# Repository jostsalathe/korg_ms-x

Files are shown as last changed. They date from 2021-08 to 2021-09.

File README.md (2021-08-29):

# Korg MS-X

An extreme MONOTRON mod by Soul Machine in form of an SMD PCB.

## credits

The schematics design and build instructions were published by Soul Machine on his project page
[Far Beyond Perception Instruments](https://www.djsoulmachine.com/farbeyondperception/msx.html)
and as 
[PDF here](http://www.djsoulmachine.com/farbeyondperception/msx/MSX-schematics.pdf).

He built it with a lot of perf board and freehand wiring.

Also special thanks to Heiner Büge who convinced me to build this mod with him. He also brought a lot of knowledge about analog synthesizers into this project and I would **not** have been able to develop this project without him!

## Where this project takes over

This project aims to take the design of Soul Machine and develop a neat printed circuit board with SMD components where sensible so that it can be produced and to a large degree even be assembled by cheap manufacturers like [JLCPCB](jlcpcb.com) or [PCBWay](pcbway.com).

## Parts

0805 chip resistors with 1% tolerance shall be used for relatively easy hand soldering.
Most capacitors are cermaic 0805. 100uF (10V) and 47uF (6V3) use 1206 package instead.

### SMD parts

| Part | Count | Refs | JLCPCB # ***extended*** (2021-08-27) |
| --- | --- | --- | --- |
| 100uF | 3 | C201, C303, C403 | ***C312983*** |
| 10uF | 10 | C202, C205-C207, C308, C401, C402, C506, C601, C702 | C15850 |
| 47uF | 2 | C203, C204 | C96123 |
| 1uF | 5 | C301, C302, C304, C305, C701 | C28323 |
| 100nF | 7 | C306, C501, C505, C507-C510 | C49678 |
| 470nF | 1 | C307 | C13967 |
| 22pF | 1 | C309 | C1804 |
| 500pF | 1 | C404 | ***C1747*** |
| 47nF | 1 | C502 | C53134 |
| 4.7nF | 1 | C503 | C1744 |
| 470pF | 1 | C504 | C1743 |
| 100pF | 1 | C703 | C1790 |
| 1N4148 | 4 | D301, D302, D401, D402 | C2128 |
| 2SC945 | 1 | Q701 | ***C181154*** |
| 10k | 22 | R201, R202, R417, R501, R505-R507, R509, R510, R512, R513, R515, R516, R518, R519, R521, R522, R524, R604, R607, R608, R610 | C17414 |
| 100k | 43 | R301-R305, R307, R309-R312, R318, R324-R331, R401, R402, R404, R406-R413, R420, R421, R502, R602, R609, R612-R614, R616, R701-R703, R706 | ***C149504*** |
| 33k | 1 | R306 | C17633 |
| 47 | 1 | R308 | C17714 |
| 5k6 | 2 | R313, R321 | C4382 |
| 4k7 | 1 | R314 | C17673 |
| 1M | 4 | R315, R322, R403, R503 | C17514 |
| 47k | 2 | R316, R618 | C17713 |
| 56k | 1 | R317 | C17756 |
| 12 | 1 | R319 | ***C204200*** |
| 39k | 2 | R320, R419 | C25826 |
| 220k | 1 | R323 | C17556 |
| 22k | 1 | R405 | C17560 |
| 2k2 | 3 | R414-R416 | C17520 |
| 180 | 2 | R418, R504 | C25270 |
| 1k | 11 | R508, R511, R514, R517, R520, R523, R525, R601, R605, R619, R707 | C17513 |
| 56 | 1 | R603 | C17757 |
| 390 | 1 | R606 | C17655 |
| 27k | 1 | R611 | C17593 |
| 330k | 1 | R615 | C17629 |
| 68k | 1 | R617 | C17801 |
| 680k | 1 | R704 | C17797 |
| 470k | 1 | R705 | C17709 |
| 150k | 1 | R708 | C17470 |
| AMS1117-5.0 | 1 | U202 | C6187 |
| LMV321 | 3 | U203, U304, U501 | C7972 |
| ICL7660S | 1 | U204 | ***C7535*** |
| LM324 | 4 | U301, U302, U401, U402 | C71035 |
| CD4040BM/TR | 1 | U303 | ***C725347*** |
| TL082 | 3 | U601, U602, U701 | ***C9385*** |

### THT parts

| Part | Count | Refs |
| --- | --- | --- |
| 10k trimmer pot  | 5 | RV303, RV401, RV601, RV603, RV605  |
| 100k trimmer pot | 3 | RV502, RV504, RV606 |
| DIP-14 IC socket | 1 | U502 |

### external parts

| Part | Count | Refs (optional) |
| --- | --- | --- |
| Korg MONOTRON | 1 | J101 |
| LED | 2 | D403, D501 |
| DC jack | 1 | J201 |
| rotary switch 3P4T | 2 | J301, J601 |
| rotary switch 4P3T | 1 | J401 |
| 1/4" mono jack | 3 | J602, J603, J701 |
| 10k pot | 9..11 | RV301, RV501, RV503, (RV505), (RV506), RV507, RV508, RV509, RV510, RV602, RV701 |
| 100k pot | 1 | RV302 |
| 20k pot | 2 | RV402, RV403 |
| 220k pot | 1 | RV604 |
| toggle switch SPST | 1..4  | (SW501), (SW502), SW601, (SW603) |
| mom. switch SPST | 1 | SW605 |
| toggle switch SP3T | 0..1  | (SW503) |
| toggle switch SPDT | 3..4  | (SW504), SW602, SW604, SW701 |
| mom. switch SPDT | 0..1  | (SW505) |

## Pictures

PCB front:

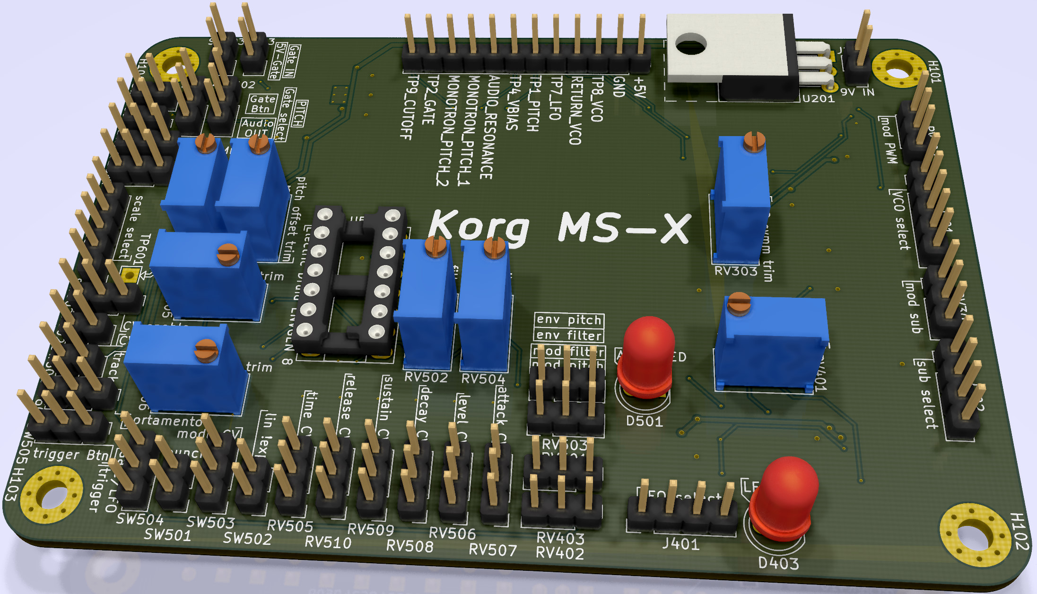
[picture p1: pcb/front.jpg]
PCB front


PCB back:

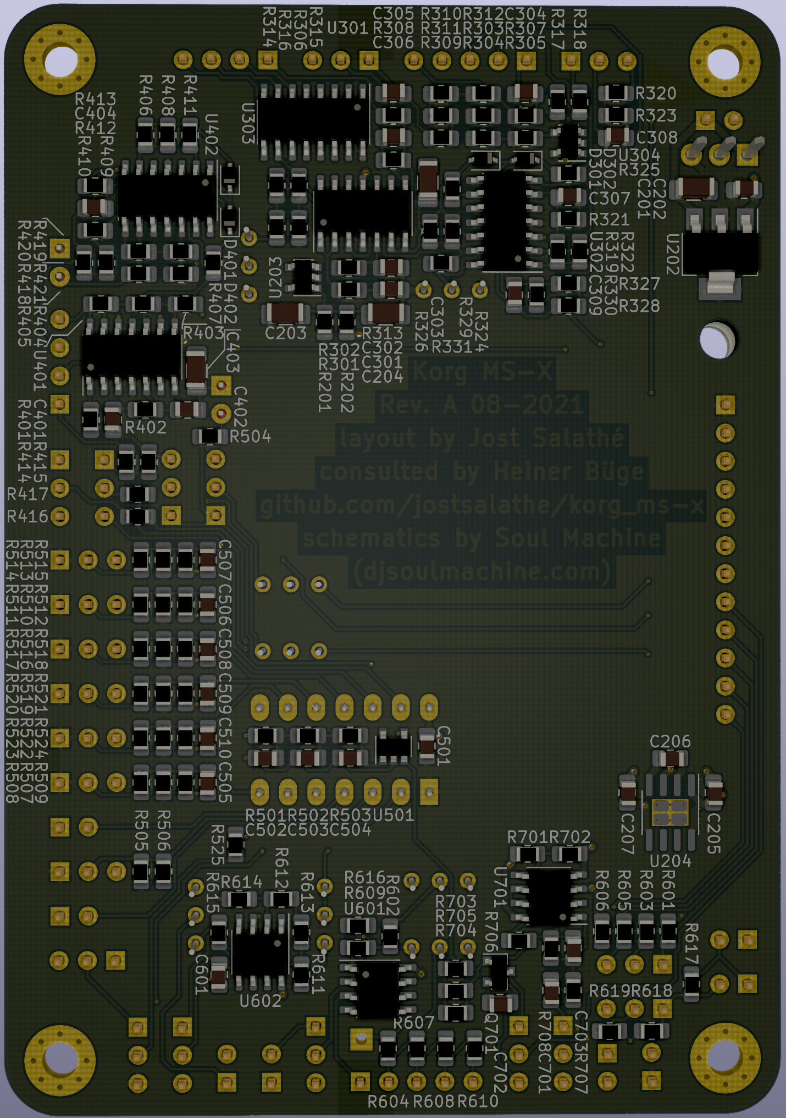
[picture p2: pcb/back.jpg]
PCB back


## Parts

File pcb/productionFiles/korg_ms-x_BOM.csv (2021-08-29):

Comment | Designator | Footprint | LCSC Part Number
100u | C201,C303,C403 | Capacitor_SMD:C_1206_3216Metric_Pad1.42x1.75mm_HandSolder | C312983
10u | C202,C205,C206,C207,C308,C401,C402,C506,C601,C702 | Capacitor_SMD:C_0805_2012Metric_Pad1.18x1.45mm_HandSolder | C15850
47u | C203,C204 | Capacitor_SMD:C_1206_3216Metric_Pad1.42x1.75mm_HandSolder | C96123
1u | C301,C302,C304,C305,C701 | Capacitor_SMD:C_0805_2012Metric_Pad1.18x1.45mm_HandSolder | C28323
100n | C306,C501,C505,C507,C508,C509,C510 | Capacitor_SMD:C_0805_2012Metric_Pad1.18x1.45mm_HandSolder | C49678
470n | C307 | Capacitor_SMD:C_0805_2012Metric_Pad1.18x1.45mm_HandSolder | C13967
22p | C309 | Capacitor_SMD:C_0805_2012Metric_Pad1.18x1.45mm_HandSolder | C1804
500p | C404 | Capacitor_SMD:C_0805_2012Metric_Pad1.18x1.45mm_HandSolder | C1747
47n | C502 | Capacitor_SMD:C_0805_2012Metric_Pad1.18x1.45mm_HandSolder | C53134
4n7 | C503 | Capacitor_SMD:C_0805_2012Metric_Pad1.18x1.45mm_HandSolder | C1744
470p | C504 | Capacitor_SMD:C_0805_2012Metric_Pad1.18x1.45mm_HandSolder | C1743
100p | C703 | Capacitor_SMD:C_0805_2012Metric_Pad1.18x1.45mm_HandSolder | C1790
1N4148WS | D301,D302,D401,D402 | Diode_SMD:D_SOD-323 | C2128
LED | D403,D501 | LED_THT:LED_D5.0mm
MountingHole_Pad | H101,H102,H103,H104 | MountingHole:MountingHole_3.2mm_M3_Pad_Via
MONOTRON | J101 | Connector_PinHeader_2.54mm:PinHeader_1x12_P2.54mm_Vertical
PWR_IN | J201 | Connector_PinHeader_2.54mm:PinHeader_1x02_P2.54mm_Vertical
VCO_SEL | J301 | Connector_PinHeader_2.54mm:PinHeader_1x05_P2.54mm_Vertical
SUB_SEL | J302 | Connector_PinHeader_2.54mm:PinHeader_1x04_P2.54mm_Vertical
LFO_SEL | J401 | Connector_PinHeader_2.54mm:PinHeader_1x04_P2.54mm_Vertical
SCALE_SEL | J601 | Connector_PinHeader_2.54mm:PinHeader_1x05_P2.54mm_Vertical
CV_IN | J602 | Connector_PinHeader_2.54mm:PinHeader_1x02_P2.54mm_Vertical
GATE_IN | J603 | Connector_PinHeader_2.54mm:PinHeader_1x02_P2.54mm_Vertical
AUDIO_OUT | J701 | Connector_PinHeader_2.54mm:PinHeader_1x02_P2.54mm_Vertical
Net-Tie_2 | NT201 | NetTie:NetTie-2_SMD_Pad0.5mm
2SC945 | Q701 | Package_TO_SOT_SMD:SOT-23 | C181154
10k | R201,R202,R417,R501,R505,R506,R507,R509,R510,R512,R513,R515,R516,R518,R519,R521,R522,R524,R604,R607,R608,R610 | Resistor_SMD:R_0805_2012Metric_Pad1.20x1.40mm_HandSolder | C17414
100k | R301,R302,R303,R304,R305,R307,R309,R310,R311,R312,R318,R324,R325,R326,R327,R328,R329,R330,R331,R401,R402,R404,R406,R407,R408,R409,R410,R411,R412,R413,R420,R421,R502,R602,R609,R612,R613,R614,R616,R701,R702,R703,R706 | Resistor_SMD:R_0805_2012Metric_Pad1.20x1.40mm_HandSolder | C149504
33k | R306 | Resistor_SMD:R_0805_2012Metric_Pad1.20x1.40mm_HandSolder | C17633
47 | R308 | Resistor_SMD:R_0805_2012Metric_Pad1.20x1.40mm_HandSolder | C17714
5k6 | R313,R321 | Resistor_SMD:R_0805_2012Metric_Pad1.20x1.40mm_HandSolder | C4382
4k7 | R314 | Resistor_SMD:R_0805_2012Metric_Pad1.20x1.40mm_HandSolder | C17673
1M | R315,R322,R403,R503 | Resistor_SMD:R_0805_2012Metric_Pad1.20x1.40mm_HandSolder | C17514
47k | R316,R618 | Resistor_SMD:R_0805_2012Metric_Pad1.20x1.40mm_HandSolder | C17713
56k | R317 | Resistor_SMD:R_0805_2012Metric_Pad1.20x1.40mm_HandSolder | C17756
12 | R319 | Resistor_SMD:R_0805_2012Metric_Pad1.20x1.40mm_HandSolder | C204200
39k | R320,R419 | Resistor_SMD:R_0805_2012Metric_Pad1.20x1.40mm_HandSolder | C25826
220k | R323 | Resistor_SMD:R_0805_2012Metric_Pad1.20x1.40mm_HandSolder | C17556
22k | R405 | Resistor_SMD:R_0805_2012Metric_Pad1.20x1.40mm_HandSolder | C17560
2k2 | R414,R415,R416 | Resistor_SMD:R_0805_2012Metric_Pad1.20x1.40mm_HandSolder | C17520
180 | R418,R504 | Resistor_SMD:R_0805_2012Metric_Pad1.20x1.40mm_HandSolder | C25270
1k | R508,R511,R514,R517,R520,R523,R525,R601,R605,R619,R707 | Resistor_SMD:R_0805_2012Metric_Pad1.20x1.40mm_HandSolder | C17513
56 | R603 | Resistor_SMD:R_0805_2012Metric_Pad1.20x1.40mm_HandSolder | C17757
390 | R606 | Resistor_SMD:R_0805_2012Metric_Pad1.20x1.40mm_HandSolder | C17655
27k | R611 | Resistor_SMD:R_0805_2012Metric_Pad1.20x1.40mm_HandSolder | C17593
330k | R615 | Resistor_SMD:R_0805_2012Metric_Pad1.20x1.40mm_HandSolder | C17629
68k | R617 | Resistor_SMD:R_0805_2012Metric_Pad1.20x1.40mm_HandSolder | C17801
680k | R704 | Resistor_SMD:R_0805_2012Metric_Pad1.20x1.40mm_HandSolder | C17797
470k | R705 | Resistor_SMD:R_0805_2012Metric_Pad1.20x1.40mm_HandSolder | C17709
150k | R708 | Resistor_SMD:R_0805_2012Metric_Pad1.20x1.40mm_HandSolder | C17470
10k | RV301,RV501,RV503,RV505,RV506,RV507,RV508,RV509,RV510,RV602,RV701 | Connector_PinHeader_2.54mm:PinHeader_1x03_P2.54mm_Vertical
100k | RV302 | Connector_PinHeader_2.54mm:PinHeader_1x03_P2.54mm_Vertical
10k | RV303,RV401,RV601,RV603,RV605 | Potentiometer_THT:Potentiometer_Bourns_3296W_Vertical
20k | RV402,RV403 | Connector_PinHeader_2.54mm:PinHeader_1x03_P2.54mm_Vertical
100k | RV502,RV504,RV606 | Potentiometer_THT:Potentiometer_Bourns_3296W_Vertical
220k | RV604 | Connector_PinHeader_2.54mm:PinHeader_1x03_P2.54mm_Vertical
SW_SPST | SW501,SW502,SW601,SW603,SW605 | Connector_PinHeader_2.54mm:PinHeader_1x02_P2.54mm_Vertical
SW_SPDT_MSM | SW503 | Connector_PinHeader_2.54mm:PinHeader_1x03_P2.54mm_Vertical
SW_SPDT | SW504,SW602,SW604,SW701 | Connector_PinHeader_2.54mm:PinHeader_1x03_P2.54mm_Vertical
SW_Push_SPDT | SW505 | Connector_PinHeader_2.54mm:PinHeader_1x03_P2.54mm_Vertical
scale4V | TP601 | TestPoint:TestPoint_THTPad_2.0x2.0mm_Drill1.0mm
L7805 | U201 | Package_TO_SOT_THT:TO-220-3_Horizontal_TabUp
AMS1117-5.0 | U202 | Package_TO_SOT_SMD:SOT-223-3_TabPin2 | C6187
LM321 | U203,U304,U501 | Package_TO_SOT_SMD:SOT-23-5 | C7972
ICL7660S | U204 | Package_SO:SOIC-8-1EP_3.9x4.9mm_P1.27mm_EP2.41x3.3mm_ThermalVias | C7535
LM324 | U301,U302,U401,U402 | Package_SO:SOIC-14_3.9x8.7mm_P1.27mm | C71035
4040 | U303 | Package_SO:SOIC-16_3.9x9.9mm_P1.27mm | C725347
ENVGEN8 | U502 | Package_DIP:DIP-14_W7.62mm_Socket_LongPads
TL082 | U601,U602,U701 | Package_SO:SOIC-8_3.9x4.9mm_P1.27mm | C9385

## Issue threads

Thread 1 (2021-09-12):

Missing polarity markings on silk screen

jostsalathe, 2021-09-12:
All pin headers should have their polarity marked on the silk screen.

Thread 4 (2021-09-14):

Simulation shows that the portamento stage is unstable

jostsalathe, 2021-09-14:
Because the feedback loop spans across `U602A` and `U602B`, and `U602A.OUT` is not connected to any feedback, that output starts to oscillate on the capacitor `C601` when `U602B.OUT` reaches the level of `pitchSum`.

`R613` should be disconnected from `U602B.IN-` and instead be connected to `U602A.OUT` to fix this behavior.

jostsalathe, 2021-09-14:
Hotfixable by desoldering `R613` and resoldering it between its `R612`-facing pad and `U602.1` which is `U602A.OUT`.

jostsalathe, 2021-09-14:
Nope, that changes the portamento behavior. `U602A.OUT` saturates during portamento to give a more linear response. The suggested change would make the response exponential and much longer, which is not desired.

jostsalathe, 2021-09-14:
Bullocks! I've been hunting ghosts! The actual circuitry has no such oscillation. But we can nontheless implement the `R613` repositioning fix since Heiner approved the logarithmic portamento behavior.

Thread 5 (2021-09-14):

`R611` for pitch gain trim should be larger

jostsalathe, 2021-09-14:
With `R611=27k` and `RV605` at its extreme, an octave on the input only results in about 14 Semitones. Making `R611` a `39k` resistor fixed the issue. This should be corrected in the design.

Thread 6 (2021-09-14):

PWM modulation is filtered too much

jostsalathe, 2021-09-14:
Reduce `C308` from 10uF to 1uF to go from `tau = 2 s` to `tau = 200 ms`.

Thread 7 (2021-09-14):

Replace KB track trimmer (`RV606`) with UI pot

jostsalathe, 2021-09-14:

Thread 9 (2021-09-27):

VCA input circuit is bullshit

jostsalathe, 2021-09-27:
- `R706` should connect `GNDA` to `D701.2` instead.
- `SW701` should be a NO switch that shorts `Q701.3` to `Q701.2` OR one that connects `Q701.1` to `+5VA` via a 1k resistor.
- There should be no directly connected input to `U701A.2`.

jostsalathe, 2021-09-27:
Hotfix will probably add a switch that shorts `Q701.2` to `Q701.3`

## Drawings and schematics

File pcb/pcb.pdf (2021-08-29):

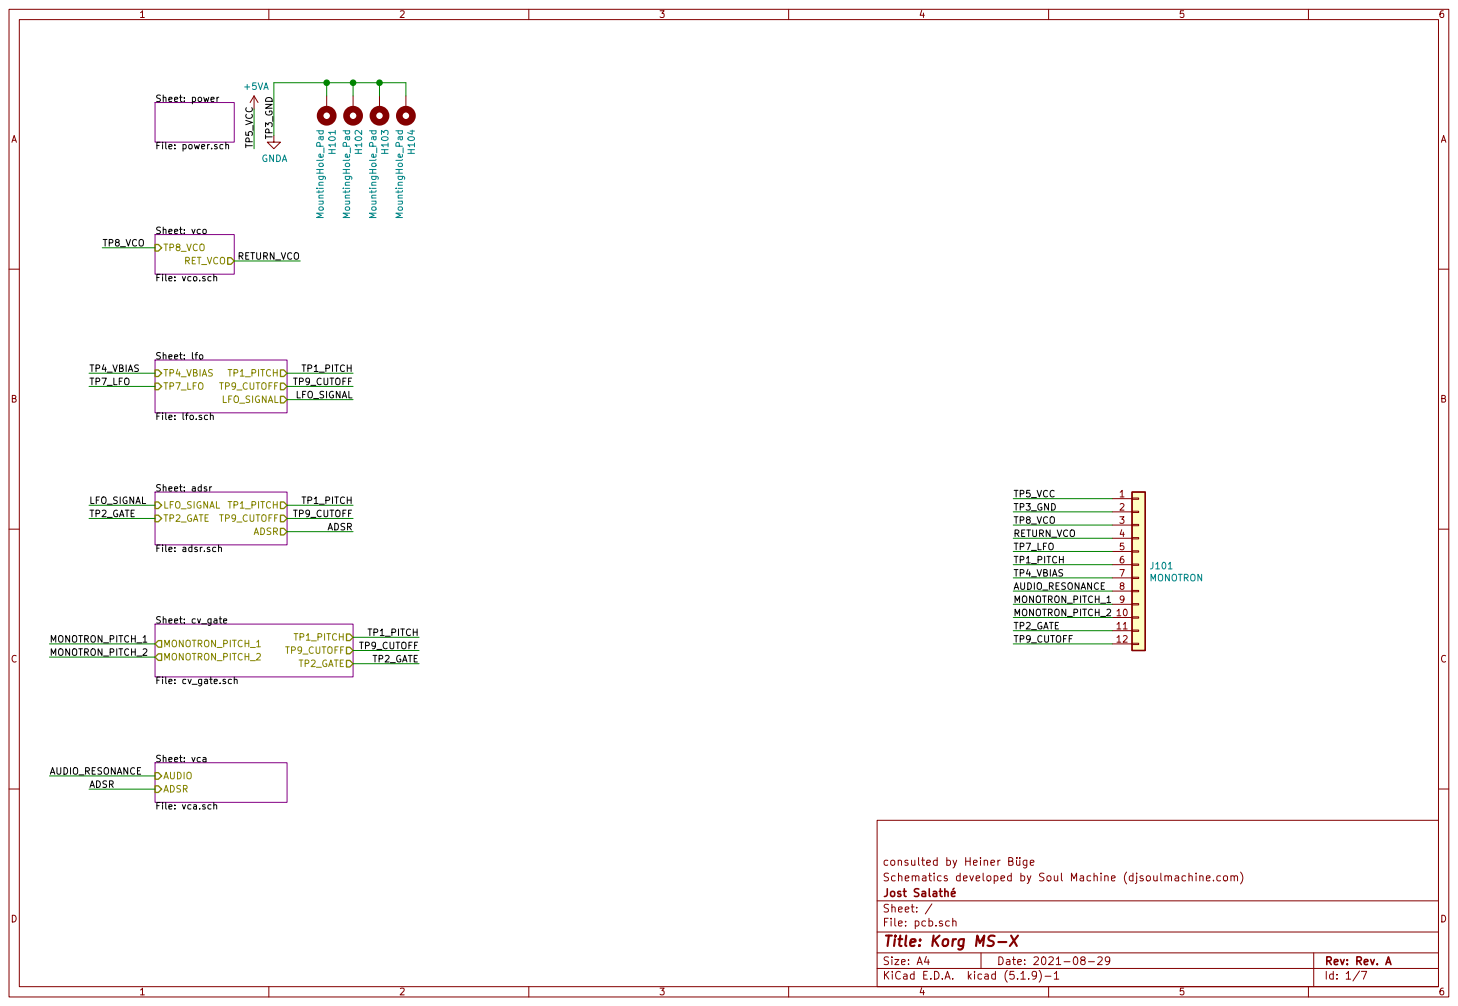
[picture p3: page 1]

Sheet: vco File: vco.sch TP8_VCO

TP2_GATE MONOTRON_PITCH_2 MONOTRON_PITCH_1 Sheet: lfo File: lfo.sch TP7_LFO

LFO_SIGNAL Sheet: adsr File: adsr.sch TP2_GATE TP9_CUTOFF

Sheet: vca File: vca.sch AUDIO

consulted by Heiner Büge
Schematics developed by Soul Machine (djsoulmachine.com)
File: pcb.sch Sheet: / Jost Salathé

Id: 1/7 Title: Korg MS-X

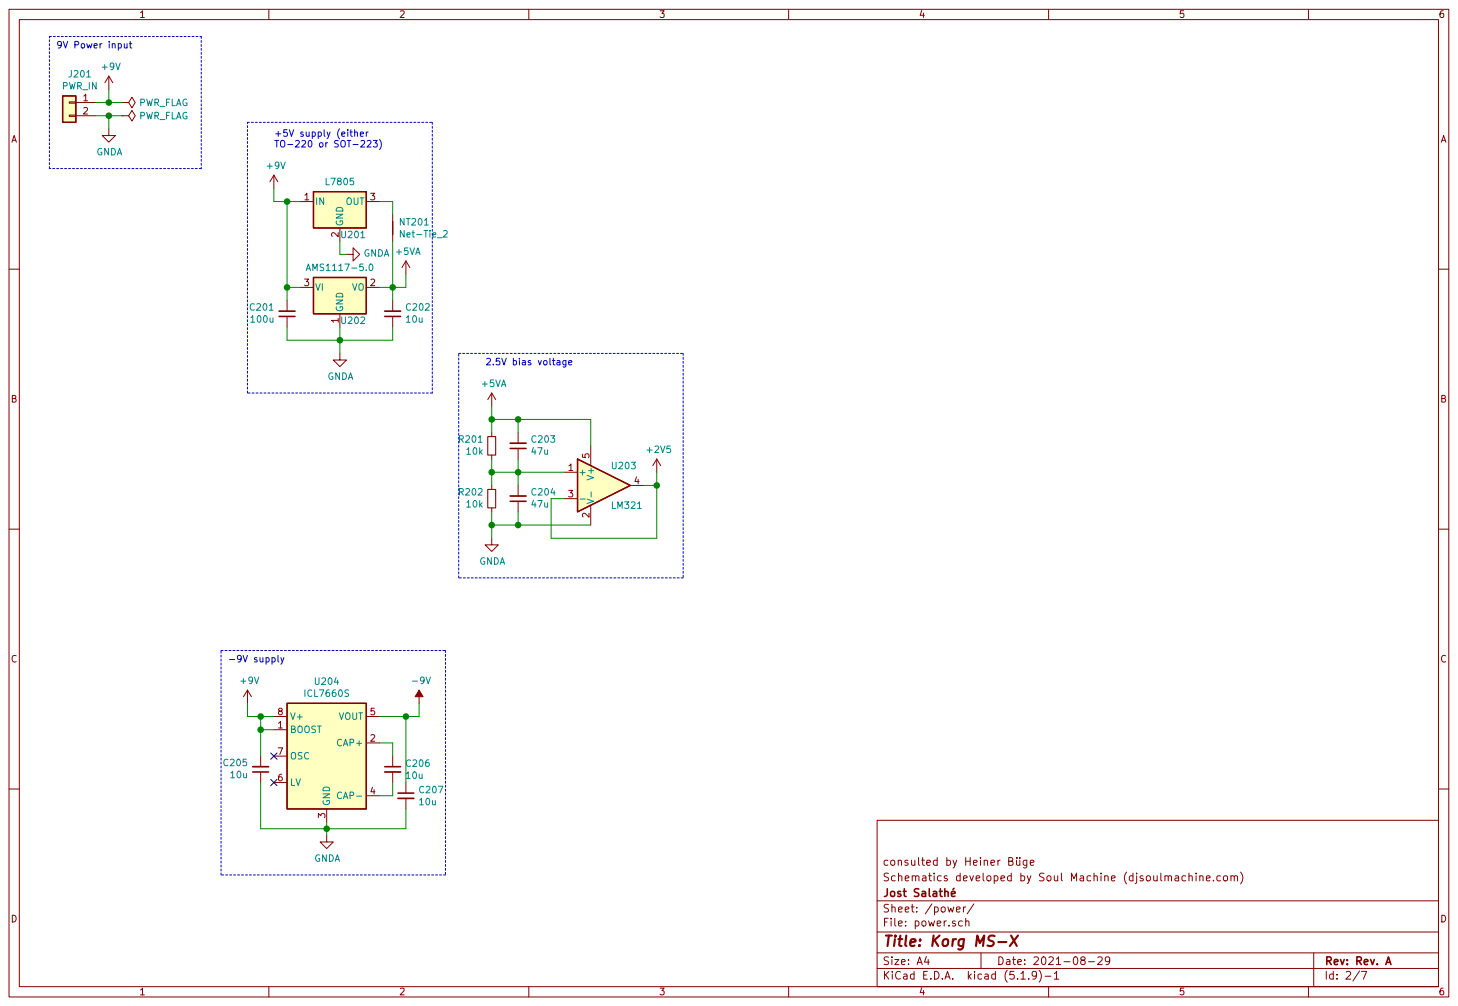
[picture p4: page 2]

consulted by Heiner Büge
Schematics developed by Soul Machine (djsoulmachine.com)
Jost Salathé
Sheet: /power/
File: power.sch
Id: 2/7 Title: Korg MS-X

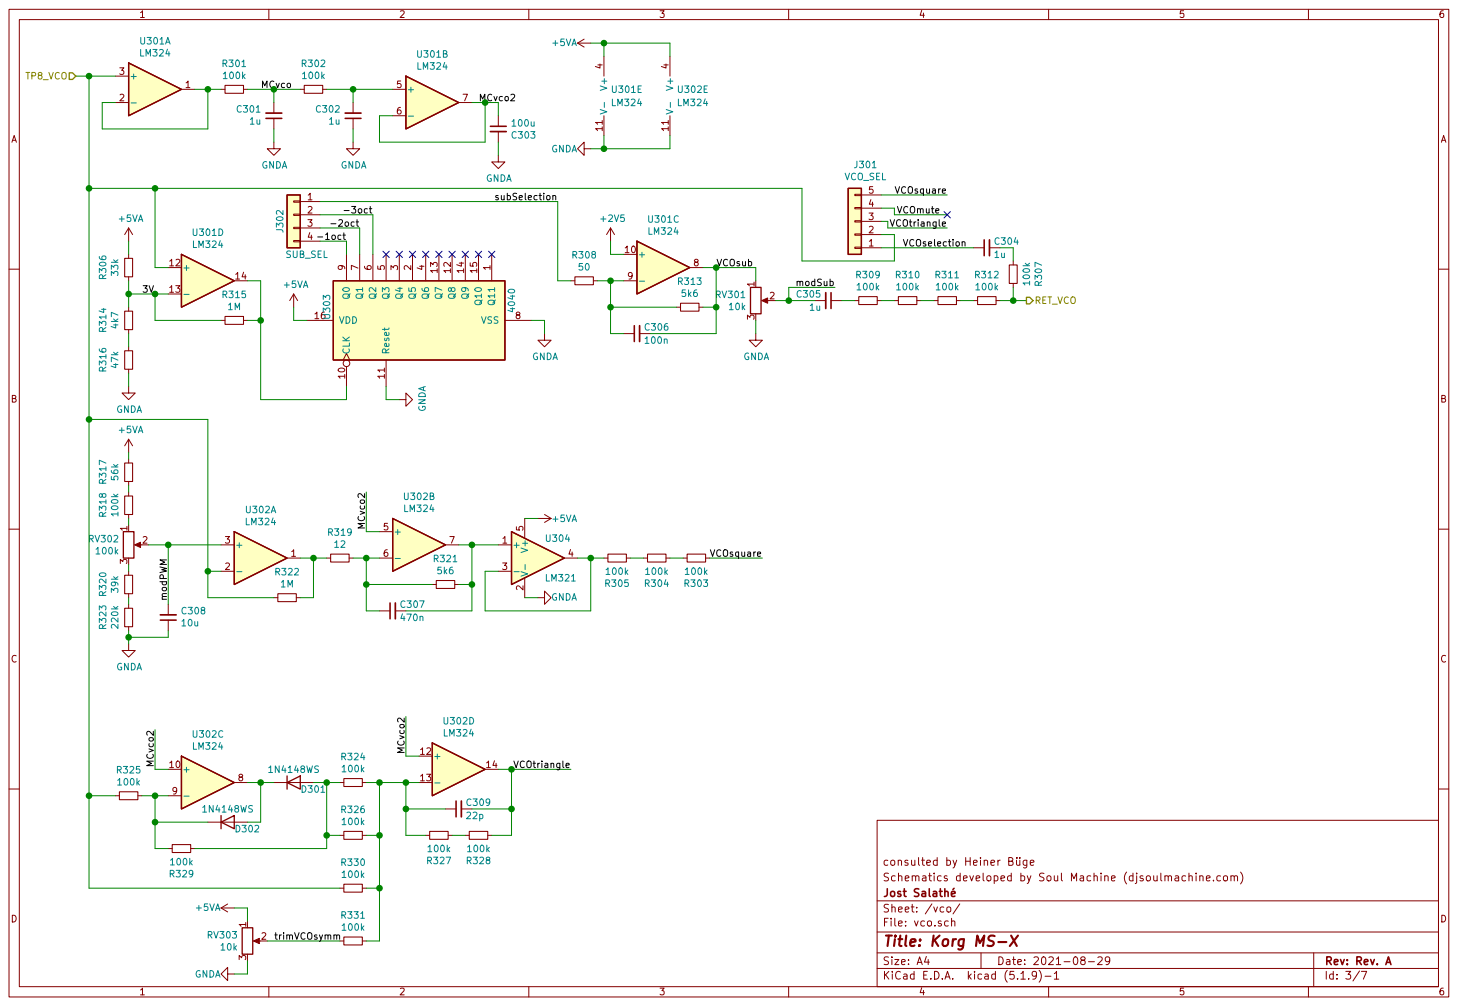
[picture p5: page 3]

consulted by Heiner Büge R326

Schematics developed by Soul Machine (djsoulmachine.com)
File: vco.sch Sheet: /vco/ Jost Salathé

Id: 3/7 Title: Korg MS-X

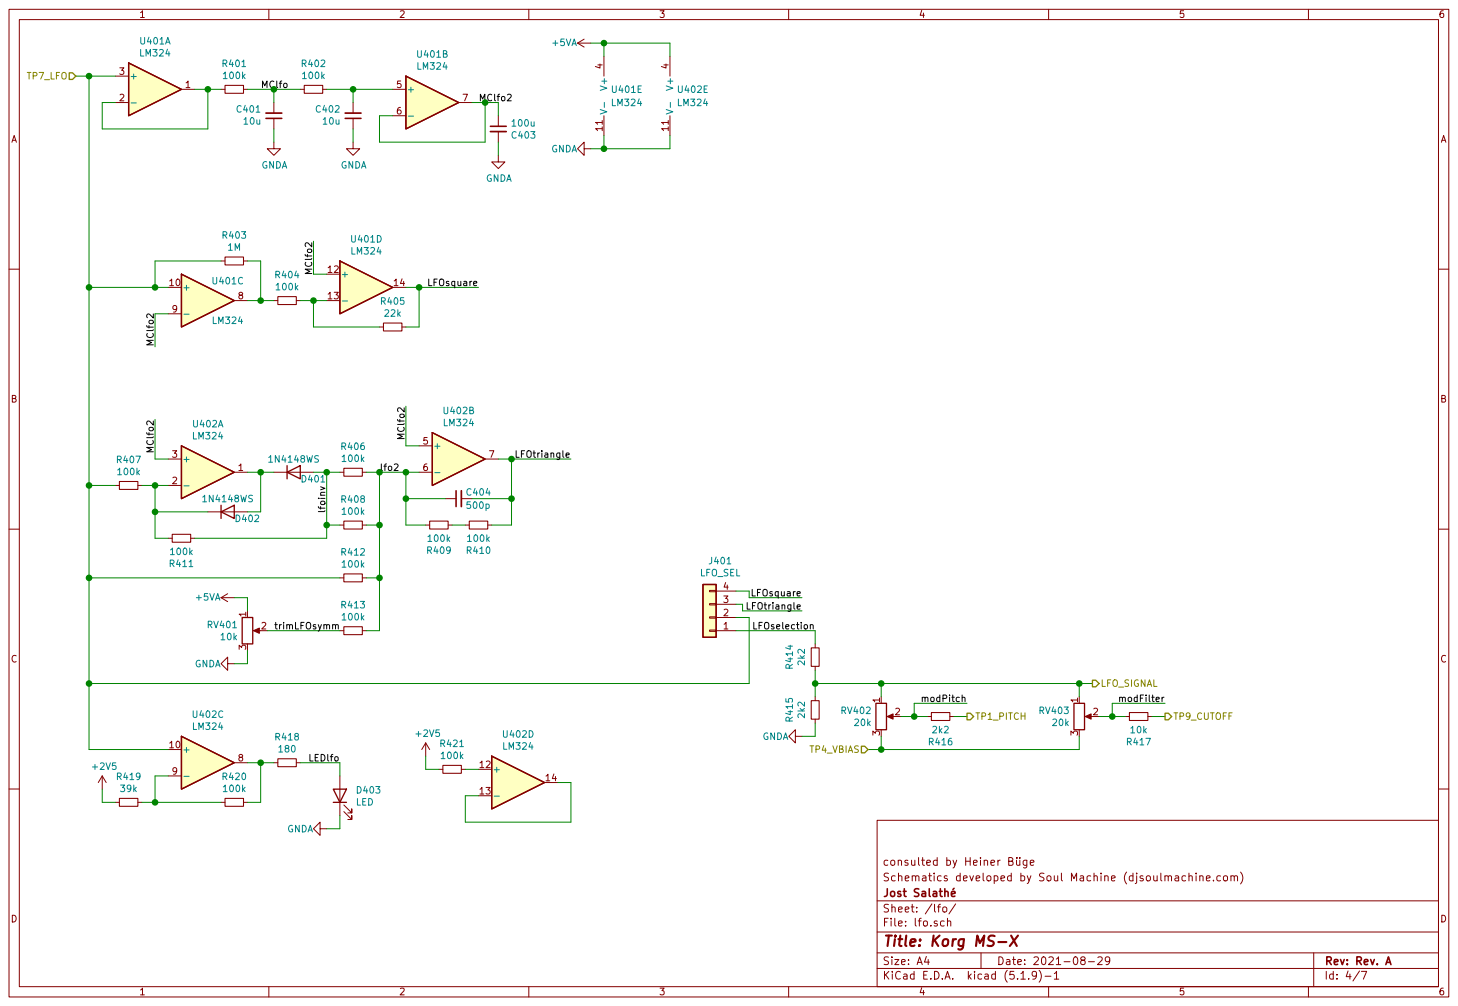
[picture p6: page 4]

consulted by Heiner Büge
Schematics developed by Soul Machine (djsoulmachine.com)
File: lfo.sch Sheet: /lfo/ Jost Salathé

Id: 4/7 Title: Korg MS-X

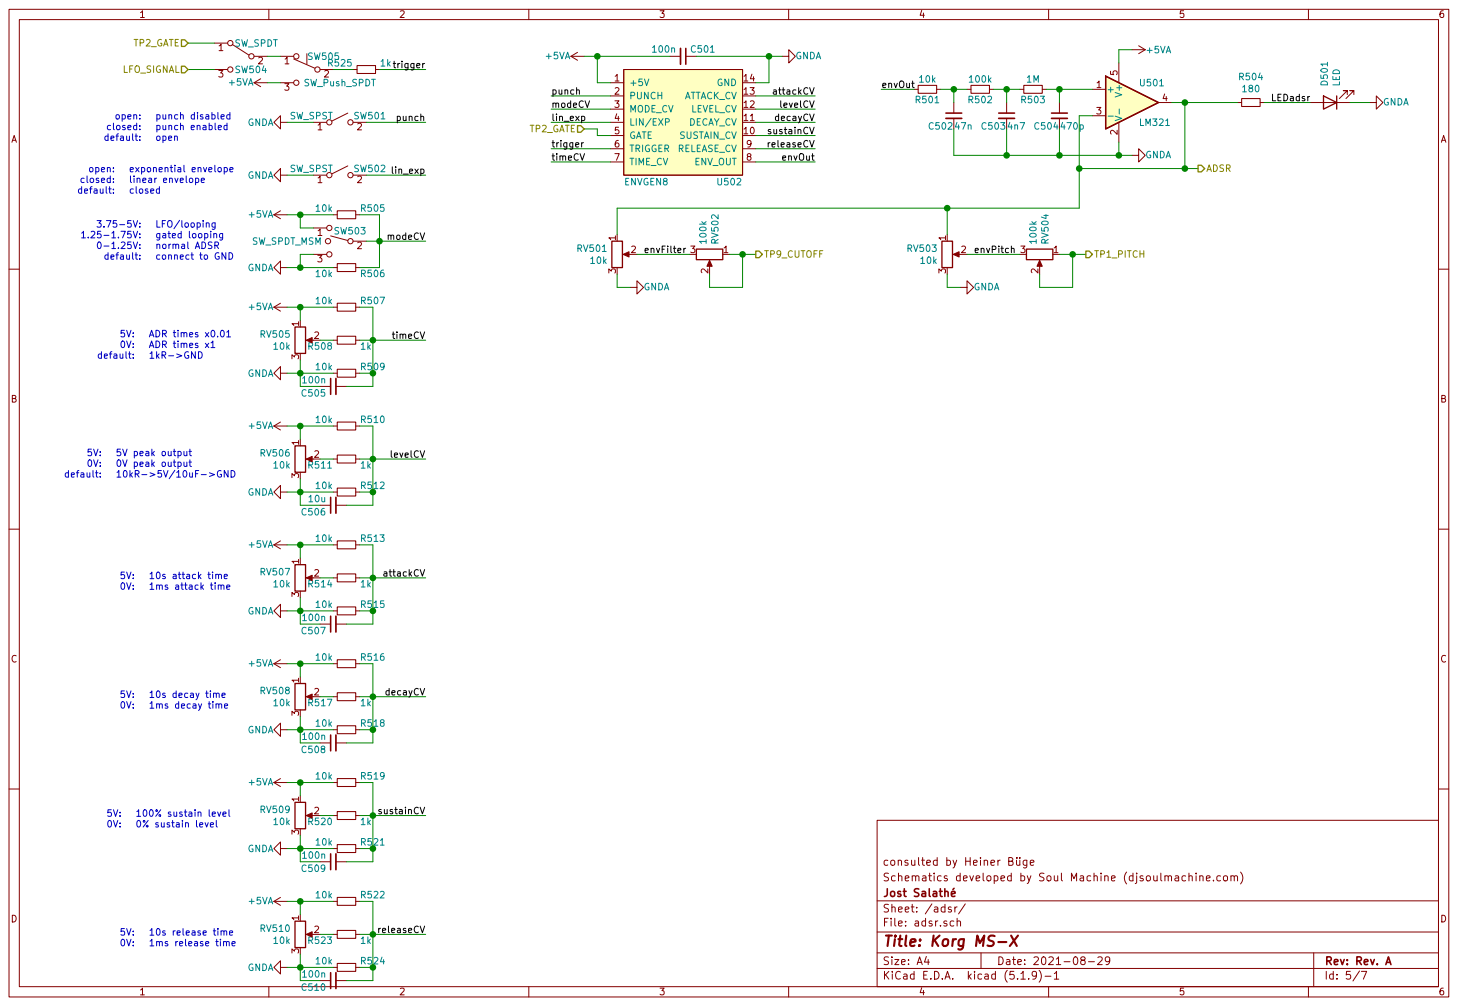
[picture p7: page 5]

TP2_GATE
open: closed: default: 5V: 0V: default: 3.75-5V: 1.25-1.75V: 0-1.25V: default: 5V peak output

exponential envelope
linear envelope
closedADR times x0.01 ADR times x1

consulted by Heiner Büge
Schematics developed by Soul Machine (djsoulmachine.com)
File: adsr.sch Sheet: /adsr/ Jost Salathé

Id: 5/7 Title: Korg MS-X

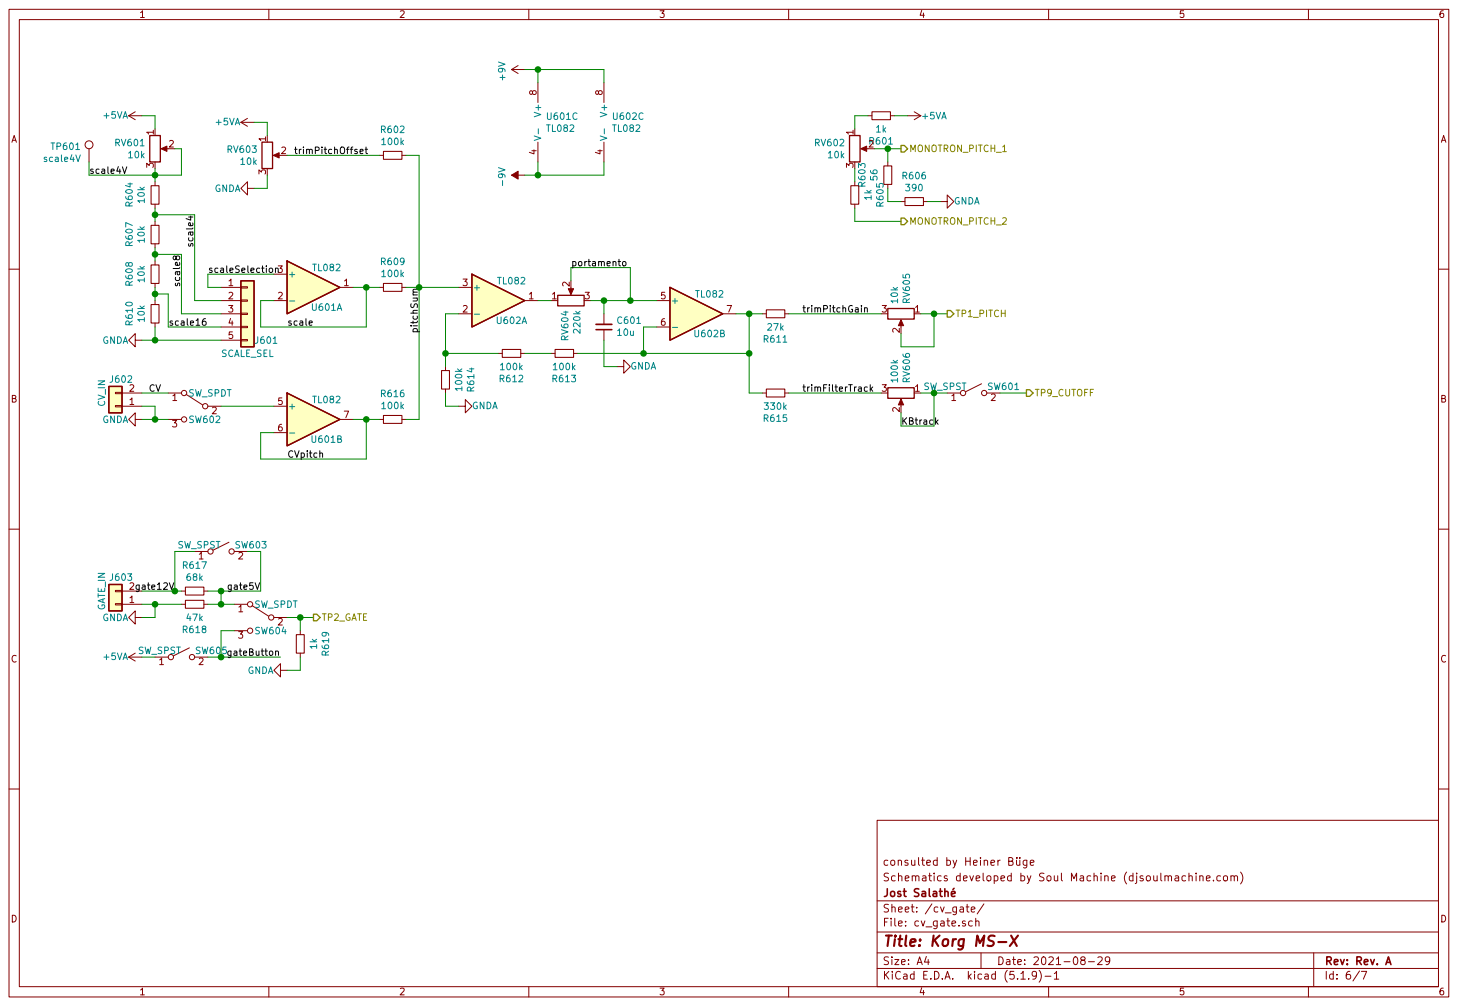
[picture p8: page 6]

consulted by Heiner Büge
Schematics developed by Soul Machine (djsoulmachine.com)
Jost Salathé
Sheet: /cv_gate/
File: cv_gate.sch
Id: 6/7 Title: Korg MS-X

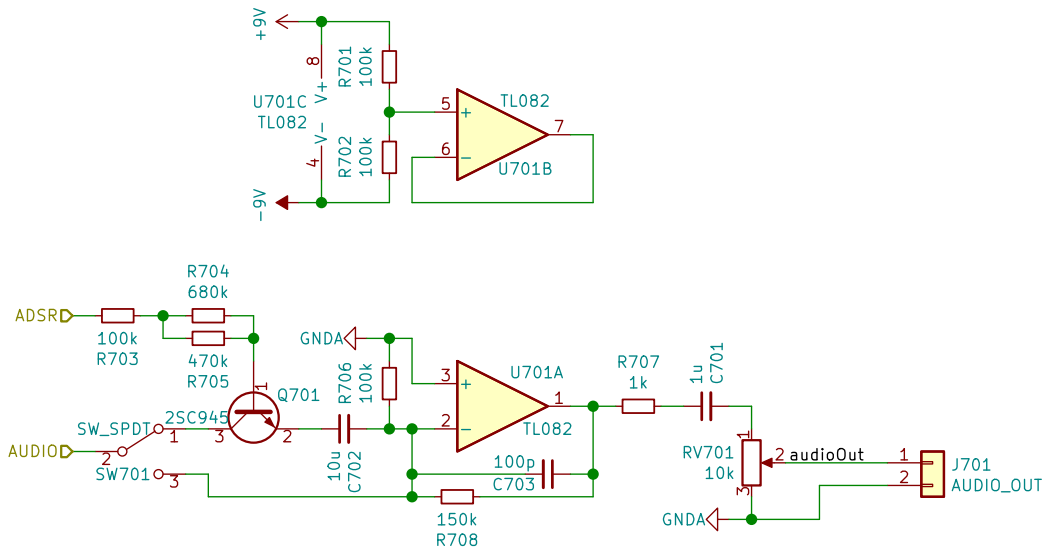
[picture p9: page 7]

consulted by Heiner Büge
Schematics developed by Soul Machine (djsoulmachine.com)
File: vca.sch Sheet: /vca/ Jost Salathé

Id: 7/7 Title: Korg MS-X

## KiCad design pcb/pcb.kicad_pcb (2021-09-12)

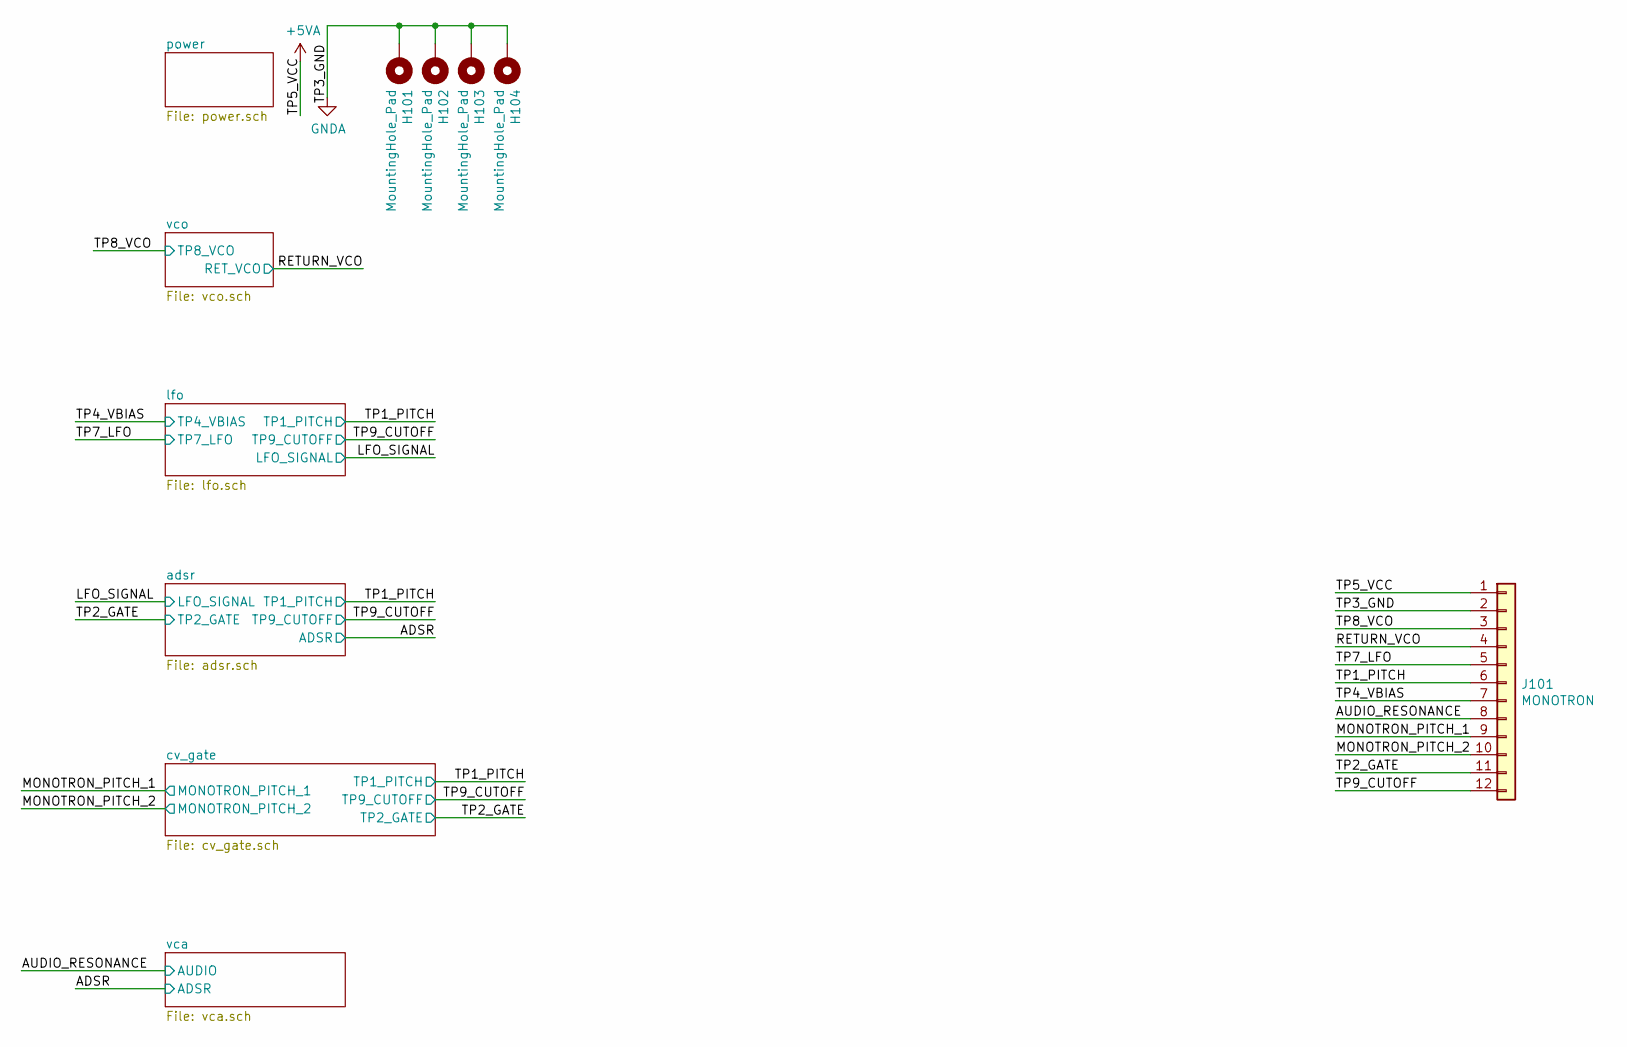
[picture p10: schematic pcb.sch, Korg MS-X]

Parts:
H101, H102, H103, H104: MountingHole_Pad; MountingHole_3.2mm_M3_Pad_Via
J101: MONOTRON; PinHeader_1x12_P2.54mm_Vertical

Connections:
+5VA: J101.1; also elsewhere on the board
/AUDIO_RESONANCE: J101.8; also elsewhere on the board
/MONOTRON_PITCH_1: J101.9; also elsewhere on the board
/MONOTRON_PITCH_2: J101.10; also elsewhere on the board
/RETURN_VCO: J101.4; also elsewhere on the board
/TP1_PITCH: J101.6; also elsewhere on the board
/TP2_GATE: J101.11; also elsewhere on the board
/TP4_VBIAS: J101.7; also elsewhere on the board
/TP7_LFO: J101.5; also elsewhere on the board
/TP8_VCO: J101.3; also elsewhere on the board
/TP9_CUTOFF: J101.12; also elsewhere on the board
GNDA: H101.1, H102.1, H103.1, H104.1, J101.2; also elsewhere on the board

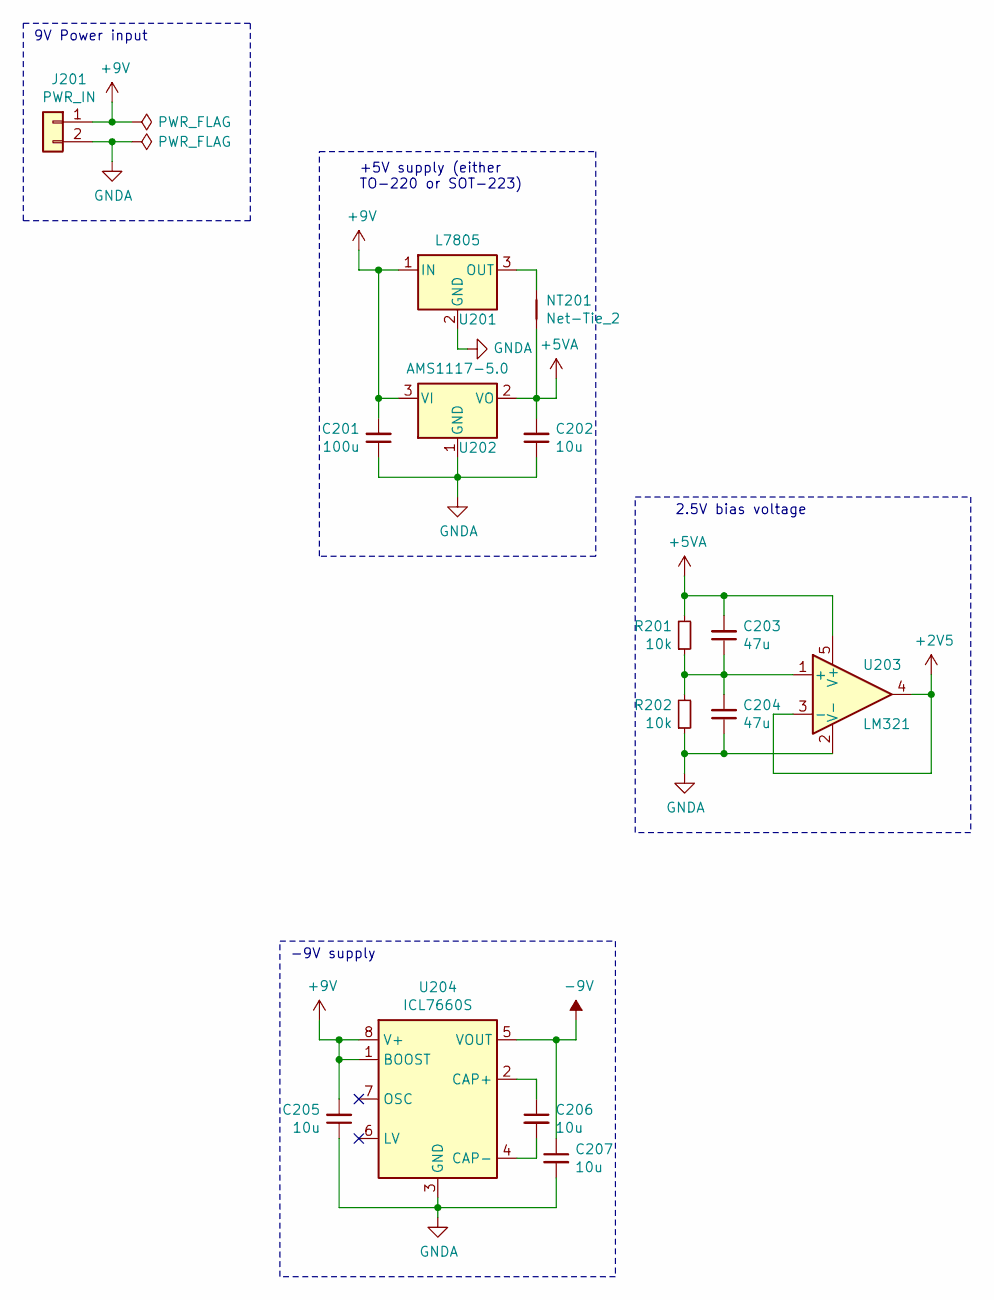
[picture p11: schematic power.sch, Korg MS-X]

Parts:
C201: 100u; C_1206_3216Metric_Pad1.42x1.75mm_HandSolder; LCSC C312983
C202, C205, C206, C207: 10u; C_0805_2012Metric_Pad1.18x1.45mm_HandSolder; LCSC C15850
C203, C204: 47u; C_1206_3216Metric_Pad1.42x1.75mm_HandSolder; LCSC C96123
J201: PWR_IN; PinHeader_1x02_P2.54mm_Vertical
NT201: Net-Tie_2; NetTie-2_SMD_Pad0.5mm
R201, R202: 10k; R_0805_2012Metric_Pad1.20x1.40mm_HandSolder; LCSC C17414
U201: L7805; TO-220-3_Horizontal_TabUp
U202: AMS1117-5.0; SOT-223-3_TabPin2; LCSC C6187
U203: LM321; SOT-23-5; LCSC C7972
U204: ICL7660S; SOIC-8-1EP_3.9x4.9mm_P1.27mm_EP2.41x3.3mm_ThermalVias; LCSC C7535

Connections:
+2V5: U203.3 (-), U203.4; also elsewhere on the board
+5VA: C202.2, C203.2, NT201.2, R201.2, U202.2 (VO), U203.5 (V+); also elsewhere on the board
+9V: C201.2, C205.2, J201.1, U201.1 (IN), U202.3 (VI), U204.1 (BOOST), U204.8 (V+); also elsewhere on the board
-9V: C207.1, U204.5 (VOUT); also elsewhere on the board
GNDA: C201.1, C202.1, C204.1, C205.1, C207.2, J201.2, R202.1, U201.2 (GND), U202.1 (GND), U203.2 (V-), U204.3 (GND); also elsewhere on the board
unnamed: C203.1, C204.2, R201.1, R202.2, U203.1 (+)
unnamed: C206.1, U204.2 (CAP+)
unnamed: C206.2, U204.4 (CAP-)
unnamed: NT201.1, U201.3 (OUT)

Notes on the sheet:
9V Power input
-9V supply
+5V supply (either TO-220 or SOT-223)
2.5V bias voltage

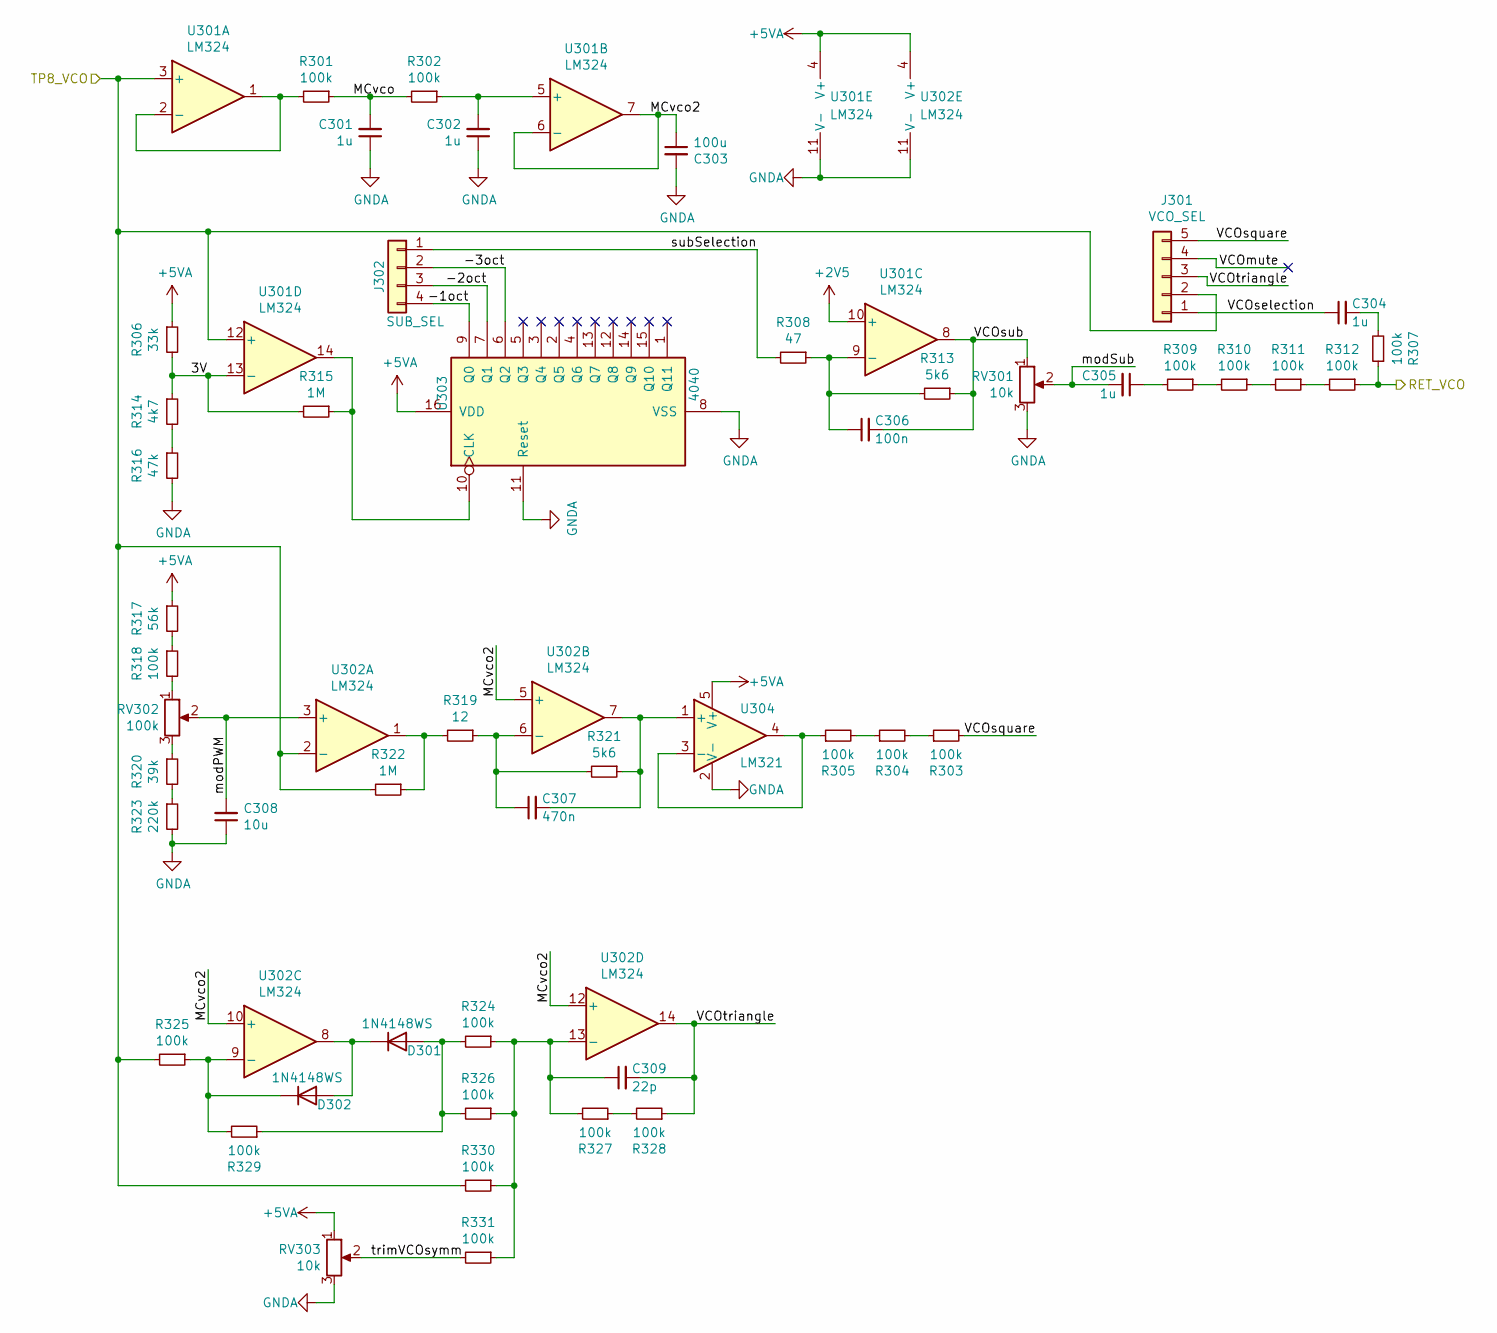
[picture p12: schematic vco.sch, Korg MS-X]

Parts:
C301, C302, C304, C305: 1u; C_0805_2012Metric_Pad1.18x1.45mm_HandSolder; LCSC C28323
C303: 100u; C_1206_3216Metric_Pad1.42x1.75mm_HandSolder; LCSC C312983
C306: 100n; C_0805_2012Metric_Pad1.18x1.45mm_HandSolder; LCSC C49678
C307: 470n; C_0805_2012Metric_Pad1.18x1.45mm_HandSolder; LCSC C13967
C308: 10u; C_0805_2012Metric_Pad1.18x1.45mm_HandSolder; LCSC C15850
C309: 22p; C_0805_2012Metric_Pad1.18x1.45mm_HandSolder; LCSC C1804
D301, D302: 1N4148WS; D_SOD-323; LCSC C2128
J301: VCO_SEL; PinHeader_1x05_P2.54mm_Vertical
J302: SUB_SEL; PinHeader_1x04_P2.54mm_Vertical
R301, R302, R303, R304, R305, R307, R309, R310, R311, R312, R318, R324, R325, R326, R327, R328, R329, R330, R331: 100k; R_0805_2012Metric_Pad1.20x1.40mm_HandSolder; LCSC C149504
R306: 33k; R_0805_2012Metric_Pad1.20x1.40mm_HandSolder; LCSC C17633
R308: 47; R_0805_2012Metric_Pad1.20x1.40mm_HandSolder; LCSC C131893
R313, R321: 5k6; R_0805_2012Metric_Pad1.20x1.40mm_HandSolder; LCSC C4382
R314: 4k7; R_0805_2012Metric_Pad1.20x1.40mm_HandSolder; LCSC C17673
R315, R322: 1M; R_0805_2012Metric_Pad1.20x1.40mm_HandSolder; LCSC C17514
R316: 47k; R_0805_2012Metric_Pad1.20x1.40mm_HandSolder; LCSC C17713
R317: 56k; R_0805_2012Metric_Pad1.20x1.40mm_HandSolder; LCSC C17756
R319: 12; R_0805_2012Metric_Pad1.20x1.40mm_HandSolder; LCSC C204200
R320: 39k; R_0805_2012Metric_Pad1.20x1.40mm_HandSolder; LCSC C25826
R323: 220k; R_0805_2012Metric_Pad1.20x1.40mm_HandSolder; LCSC C17556
RV301: 10k; PinHeader_1x03_P2.54mm_Vertical
RV302: 100k; PinHeader_1x03_P2.54mm_Vertical
RV303: 10k; Potentiometer_Bourns_3296W_Vertical
U301, U302: LM324; SOIC-14_3.9x8.7mm_P1.27mm; LCSC C71035
U303: 4040; SOIC-16_3.9x9.9mm_P1.27mm; LCSC C725347
U304: LM321; SOT-23-5; LCSC C7972

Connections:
+2V5: U301.10 (+); also elsewhere on the board
+5VA: R306.1, R317.1, RV303.1, U301.4 (V+), U302.4 (V+), U303.16 (VDD), U304.5 (V+); also elsewhere on the board
/RETURN_VCO: R307.1, R312.1; also elsewhere on the board
/TP8_VCO: J301.2, R322.2, R325.2, R330.2, U301.3 (+), U301.12 (+), U302.2 (-); also elsewhere on the board
/vco/3V: R306.2, R314.1, R315.2, U301.13 (-)
/vco/-1oct: J302.4, U303.9 (Q0)
/vco/-2oct: J302.3, U303.7 (Q1)
/vco/-3oct: J302.2, U303.6 (Q2)
/vco/MCvco: C301.2, R301.1, R302.2
/vco/MCvco2: C303.1, U301.6 (-), U301.7, U302.5 (+), U302.10 (+), U302.12 (+)
/vco/VCOmute: J301.4
/vco/VCOselection: C304.1, J301.1
/vco/VCOsquare: J301.5, R303.2
/vco/VCOsub: C306.2, R313.1, RV301.1, U301.8
/vco/VCOtriangle: C309.2, J301.3, R328.1, U302.14
/vco/modPWM: C308.2, RV302.2, U302.3 (+)
/vco/modSub: C305.2, RV301.2
/vco/subSelection: J302.1, R308.2
/vco/trimVCOsymm: R331.2, RV303.2
GNDA: C301.1, C302.1, C303.2, C308.1, R316.2, R323.2, RV301.3, RV303.3, U301.11 (V-), U302.11 (V-), U303.8 (VSS), U303.11 (Reset), U304.2 (V-); also elsewhere on the board
unnamed: C302.2, R302.1, U301.5 (+)
unnamed: C304.2, R307.2
unnamed: C305.1, R309.2
unnamed: C306.1, R308.1, R313.2, U301.9 (-)
unnamed: C307.1, R319.1, R321.2, U302.6 (-)
unnamed: C307.2, R321.1, U302.7, U304.1 (+)
unnamed: C309.1, R324.1, R326.1, R327.2, R330.1, R331.1, U302.13 (-)
unnamed: D301.1 (K), D302.2 (A), U302.8
unnamed: D301.2 (A), R324.2, R326.2, R329.1
unnamed: D302.1 (K), R325.1, R329.2, U302.9 (-)
unnamed: R301.2, U301.1, U301.2 (-)
unnamed: R303.1, R304.2
unnamed: R304.1, R305.2
unnamed: R305.1, U304.3 (-), U304.4
unnamed: R309.1, R310.2
unnamed: R310.1, R311.2
unnamed: R311.1, R312.2
unnamed: R314.2, R316.1
unnamed: R315.1, U301.14, U303.10 (CLK)
unnamed: R317.2, R318.1
unnamed: R318.2, RV302.1
unnamed: R319.2, R322.1, U302.1
unnamed: R320.1, RV302.3
unnamed: R320.2, R323.1
unnamed: R327.1, R328.2

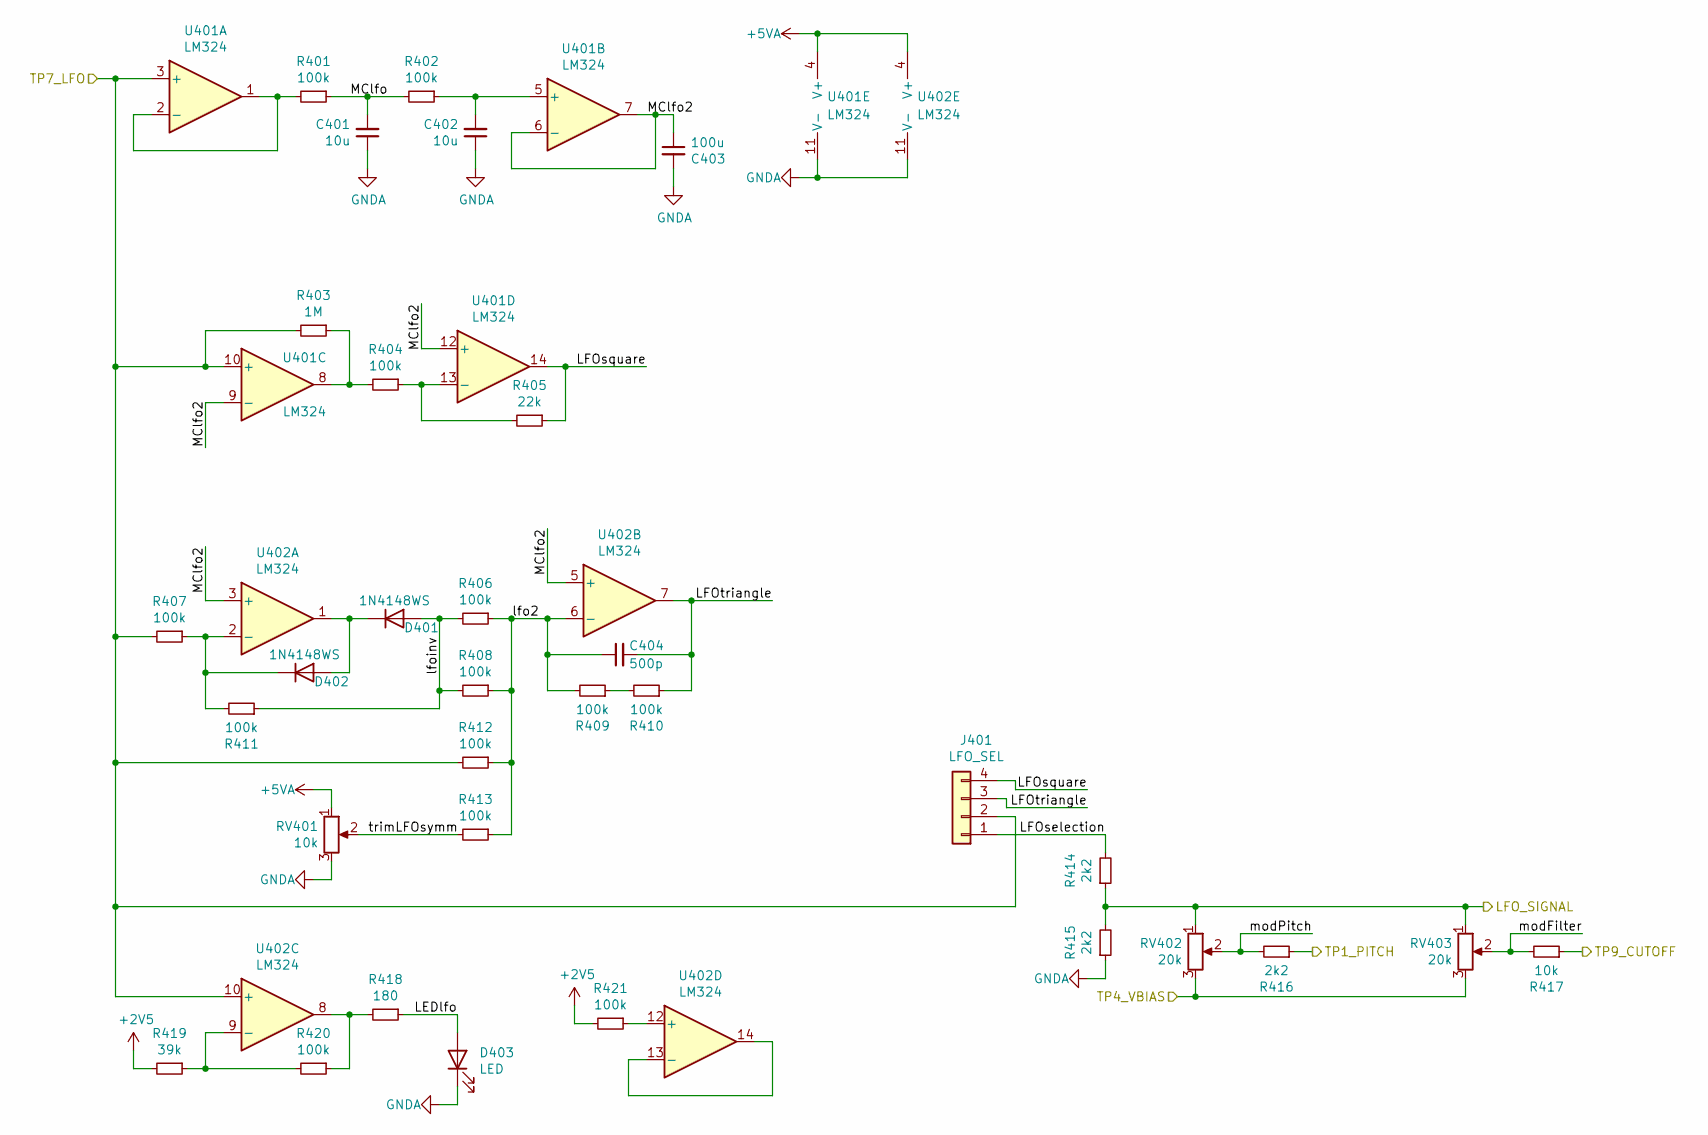
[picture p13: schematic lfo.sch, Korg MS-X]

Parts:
C401, C402: 10u; C_0805_2012Metric_Pad1.18x1.45mm_HandSolder; LCSC C15850
C403: 100u; C_1206_3216Metric_Pad1.42x1.75mm_HandSolder; LCSC C312983
C404: 500p; C_0805_2012Metric_Pad1.18x1.45mm_HandSolder; LCSC C1747
D401, D402: 1N4148WS; D_SOD-323; LCSC C2128
D403: LED; LED_D5.0mm
J401: LFO_SEL; PinHeader_1x04_P2.54mm_Vertical
R401, R402, R404, R406, R407, R408, R409, R410, R411, R412, R413, R420, R421: 100k; R_0805_2012Metric_Pad1.20x1.40mm_HandSolder; LCSC C149504
R403: 1M; R_0805_2012Metric_Pad1.20x1.40mm_HandSolder; LCSC C17514
R405: 22k; R_0805_2012Metric_Pad1.20x1.40mm_HandSolder; LCSC C17560
R414, R415, R416: 2k2; R_0805_2012Metric_Pad1.20x1.40mm_HandSolder; LCSC C17520
R417: 10k; R_0805_2012Metric_Pad1.20x1.40mm_HandSolder; LCSC C17414
R418: 180; R_0805_2012Metric_Pad1.20x1.40mm_HandSolder; LCSC C25270
R419: 39k; R_0805_2012Metric_Pad1.20x1.40mm_HandSolder; LCSC C25826
RV401: 10k; Potentiometer_Bourns_3296W_Vertical
RV402, RV403: 20k; PinHeader_1x03_P2.54mm_Vertical
U401, U402: LM324; SOIC-14_3.9x8.7mm_P1.27mm; LCSC C71035

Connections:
+2V5: R419.2, R421.2; also elsewhere on the board
+5VA: RV401.1, U401.4 (V+), U402.4 (V+); also elsewhere on the board
/LFO_SIGNAL: R414.1, R415.2, RV402.1, RV403.1; also elsewhere on the board
/TP1_PITCH: R416.1; also elsewhere on the board
/TP4_VBIAS: RV402.3, RV403.3; also elsewhere on the board
/TP7_LFO: J401.2, R403.2, R407.2, R412.2, U401.3 (+), U401.10 (+), U402.10 (+); also elsewhere on the board
/TP9_CUTOFF: R417.1; also elsewhere on the board
/lfo/LEDlfo: D403.2 (A), R418.1
/lfo/LFOselection: J401.1, R414.2
/lfo/LFOsquare: J401.4, R405.1, U401.14
/lfo/LFOtriangle: C404.2, J401.3, R410.1, U402.7
/lfo/MClfo: C401.2, R401.1, R402.2
/lfo/MClfo2: C403.1, U401.6 (-), U401.7, U401.9 (-), U401.12 (+), U402.3 (+), U402.5 (+)
/lfo/lfo2: C404.1, R406.1, R408.1, R409.2, R412.1, R413.1, U402.6 (-)
/lfo/lfoinv: D401.2 (A), R406.2, R408.2, R411.1
/lfo/modFilter: R417.2, RV403.2
/lfo/modPitch: R416.2, RV402.2
/lfo/trimLFOsymm: R413.2, RV401.2
GNDA: C401.1, C402.1, C403.2, D403.1 (K), R415.1, RV401.3, U401.11 (V-), U402.11 (V-); also elsewhere on the board
unnamed: C402.2, R402.1, U401.5 (+)
unnamed: D401.1 (K), D402.2 (A), U402.1
unnamed: D402.1 (K), R407.1, R411.2, U402.2 (-)
unnamed: R401.2, U401.1, U401.2 (-)
unnamed: R403.1, R404.2, U401.8
unnamed: R404.1, R405.2, U401.13 (-)
unnamed: R409.1, R410.2
unnamed: R418.2, R420.1, U402.8
unnamed: R419.1, R420.2, U402.9 (-)
unnamed: R421.1, U402.12 (+)
unnamed: U402.13 (-), U402.14

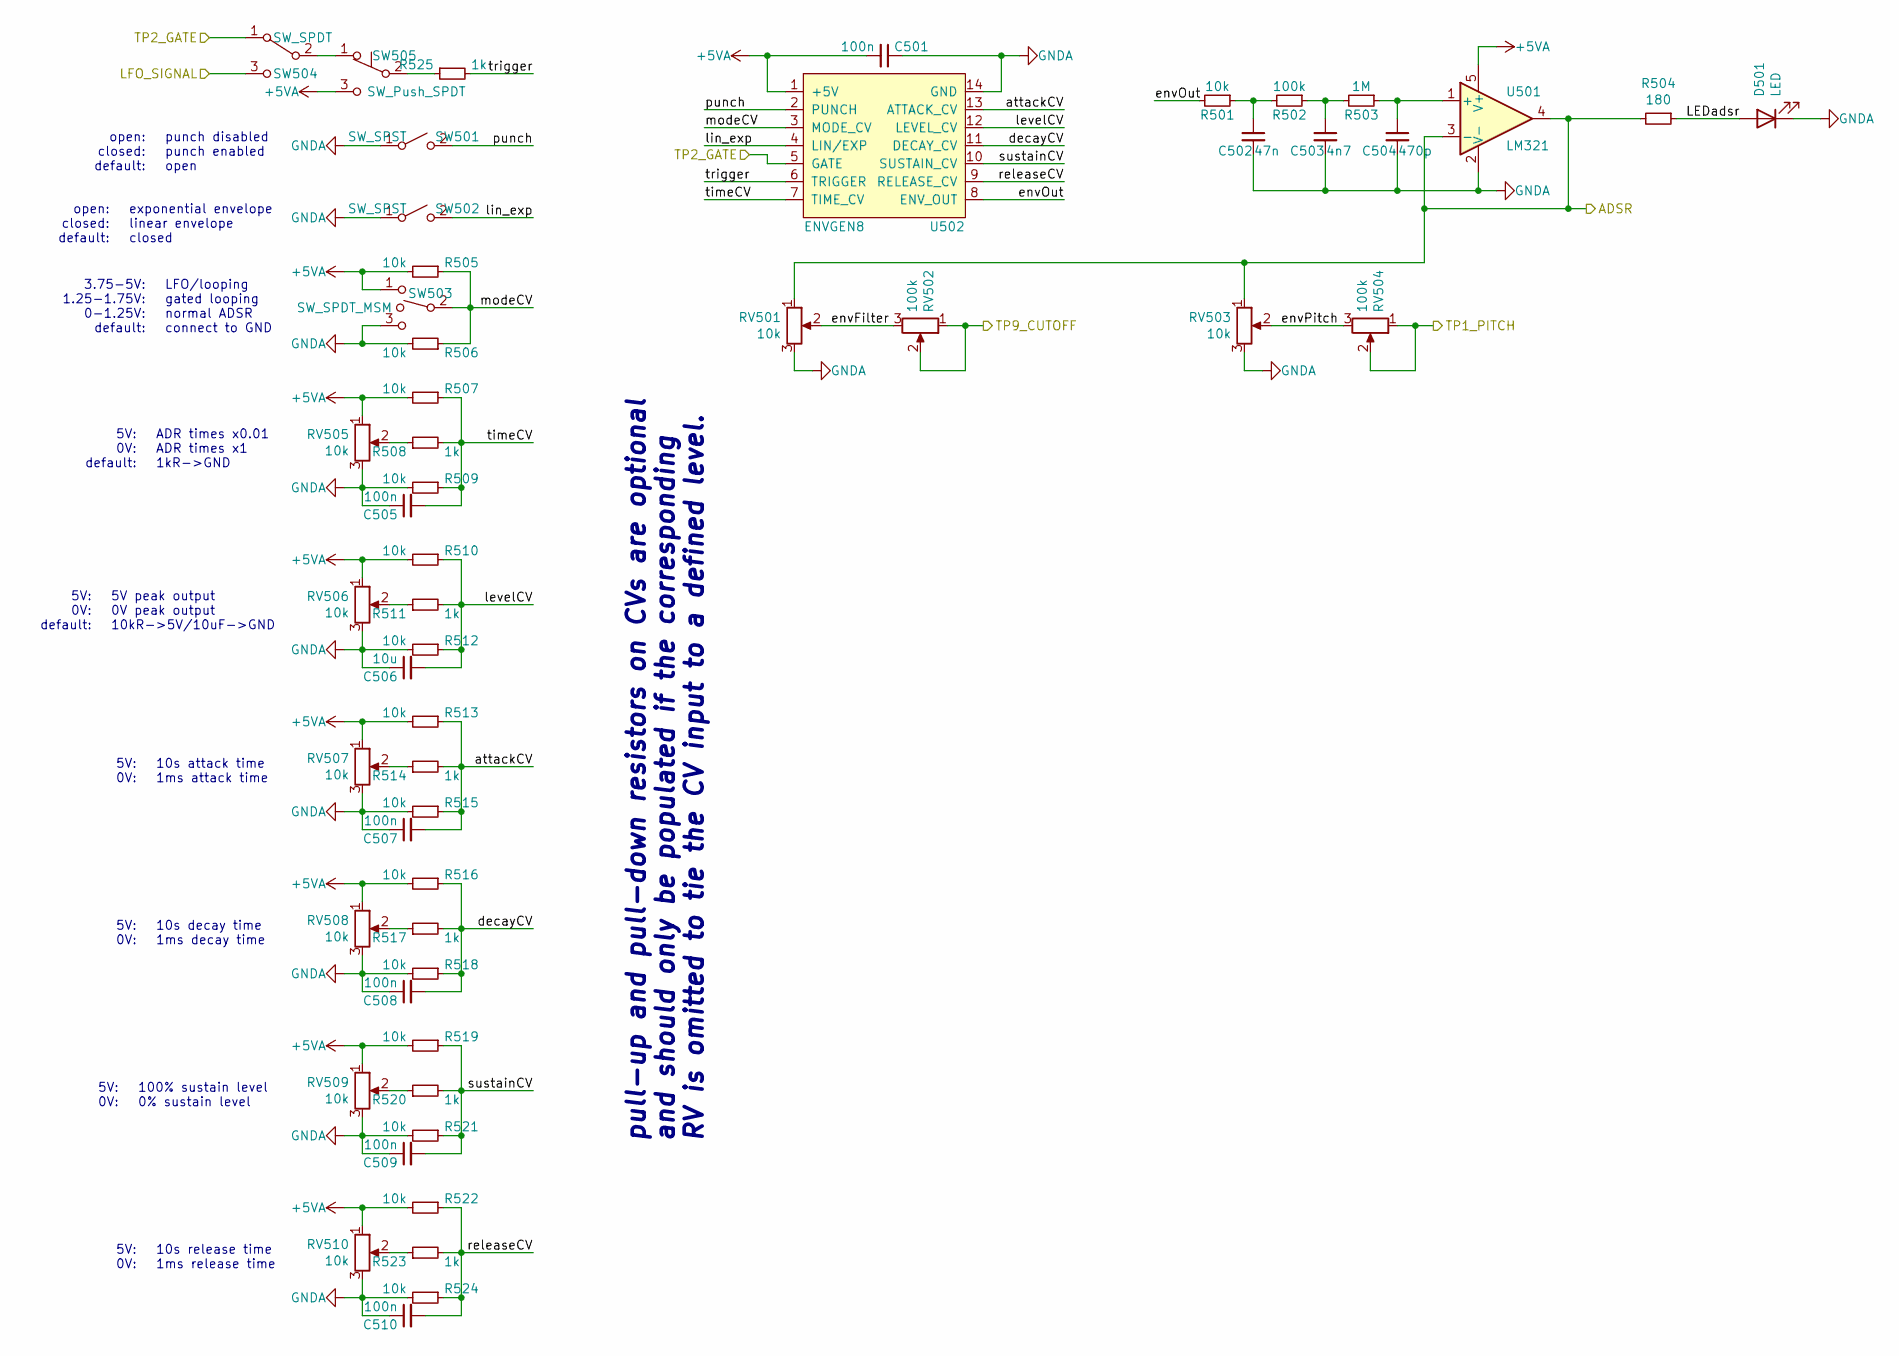
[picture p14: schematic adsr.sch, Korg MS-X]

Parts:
C501, C505, C507, C508, C509, C510: 100n; C_0805_2012Metric_Pad1.18x1.45mm_HandSolder; LCSC C49678
C502: 47n; C_0805_2012Metric_Pad1.18x1.45mm_HandSolder; LCSC C53134
C503: 4n7; C_0805_2012Metric_Pad1.18x1.45mm_HandSolder; LCSC C1744
C504: 470p; C_0805_2012Metric_Pad1.18x1.45mm_HandSolder; LCSC C1743
C506: 10u; C_0805_2012Metric_Pad1.18x1.45mm_HandSolder; LCSC C15850
D501: LED; LED_D5.0mm
R501, R505, R506, R507, R509, R510, R512, R513, R515, R516, R518, R519, R521, R522, R524: 10k; R_0805_2012Metric_Pad1.20x1.40mm_HandSolder; LCSC C17414
R502: 100k; R_0805_2012Metric_Pad1.20x1.40mm_HandSolder; LCSC C149504
R503: 1M; R_0805_2012Metric_Pad1.20x1.40mm_HandSolder; LCSC C17514
R504: 180; R_0805_2012Metric_Pad1.20x1.40mm_HandSolder; LCSC C25270
R508, R511, R514, R517, R520, R523, R525: 1k; R_0805_2012Metric_Pad1.20x1.40mm_HandSolder; LCSC C17513
RV501, RV503, RV505, RV506, RV507, RV508, RV509, RV510: 10k; PinHeader_1x03_P2.54mm_Vertical
RV502, RV504: 100k; Potentiometer_Bourns_3296W_Vertical
SW501, SW502: SW_SPST; PinHeader_1x02_P2.54mm_Vertical
SW503: SW_SPDT_MSM; PinHeader_1x03_P2.54mm_Vertical
SW504: SW_SPDT; PinHeader_1x03_P2.54mm_Vertical
SW505: SW_Push_SPDT; PinHeader_1x03_P2.54mm_Vertical
U501: LM321; SOT-23-5; LCSC C7972
U502: ENVGEN8; DIP-14_W7.62mm_Socket_LongPads

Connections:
+5VA: C501.2, R505.2, R507.2, R510.2, R513.2, R516.2, R519.2, R522.2, RV505.1, RV506.1, RV507.1, RV508.1, RV509.1, RV510.1, SW503.1, SW505.3 (C), U501.5 (V+), U502.1 (+5V); also elsewhere on the board
/ADSR: R504.2, RV501.1, RV503.1, U501.3 (-), U501.4; also elsewhere on the board
/LFO_SIGNAL: SW504.3 (C); also elsewhere on the board
/TP1_PITCH: RV504.1, RV504.2; also elsewhere on the board
/TP2_GATE: SW504.1 (A), U502.5 (GATE); also elsewhere on the board
/TP9_CUTOFF: RV502.1, RV502.2; also elsewhere on the board
/adsr/LEDadsr: D501.2 (A), R504.1
/adsr/attackCV: C507.2, R513.1, R514.2, R515.1, U502.13 (ATTACK_CV)
/adsr/decayCV: C508.2, R516.1, R517.2, R518.1, U502.11 (DECAY_CV)
/adsr/envFilter: RV501.2, RV502.3
/adsr/envOut: R501.2, U502.8 (ENV_OUT)
/adsr/envPitch: RV503.2, RV504.3
/adsr/levelCV: C506.2, R510.1, R511.2, R512.1, U502.12 (LEVEL_CV)
/adsr/lin_exp: SW502.2 (B), U502.4 (LIN/EXP)
/adsr/modeCV: R505.1, R506.1, SW503.2, U502.3 (MODE_CV)
/adsr/punch: SW501.2 (B), U502.2 (PUNCH)
/adsr/releaseCV: C510.2, R522.1, R523.2, R524.1, U502.9 (RELEASE_CV)
/adsr/sustainCV: C509.2, R519.1, R520.2, R521.1, U502.10 (SUSTAIN_CV)
/adsr/timeCV: C505.2, R507.1, R508.2, R509.1, U502.7 (TIME_CV)
/adsr/trigger: R525.2, U502.6 (TRIGGER)
GNDA: C501.1, C502.2, C503.2, C504.2, C505.1, C506.1, C507.1, C508.1, C509.1, C510.1, D501.1 (K), R506.2, R509.2, R512.2, R515.2, R518.2, R521.2, R524.2, RV501.3, RV503.3, RV505.3, RV506.3, RV507.3, RV508.3, RV509.3, RV510.3, SW501.1 (A), SW502.1 (A), SW503.3, U501.2 (V-), U502.14 (GND); also elsewhere on the board
unnamed: C502.1, R501.1, R502.2
unnamed: C503.1, R502.1, R503.2
unnamed: C504.1, R503.1, U501.1 (+)
unnamed: R508.1, RV505.2
unnamed: R511.1, RV506.2
unnamed: R514.1, RV507.2
unnamed: R517.1, RV508.2
unnamed: R520.1, RV509.2
unnamed: R523.1, RV510.2
unnamed: R525.1, SW505.2 (B)
unnamed: SW504.2 (B), SW505.1 (A)

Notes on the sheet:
punch disabled punch enabled open
exponential envelope linear envelope closed
LFO/looping gated looping normal ADSR connect to GND
open: closed: default:
3.75-5V: 1.25-1.75V: 0-1.25V: default:
ADR times x0.01 ADR times x1 1kR->GND
5V: 0V: default:
5V peak output 0V peak output 10kR->5V/10uF->GND
10s attack time 1ms attack time
5V: 0V:
10s decay time 1ms decay time
10s release time 1ms release time
100% sustain level 0% sustain level
pull-up and pull-down resistors on CVs are optional and should only be populated if the corresponding RV is omitted to tie the CV input to a defined level.

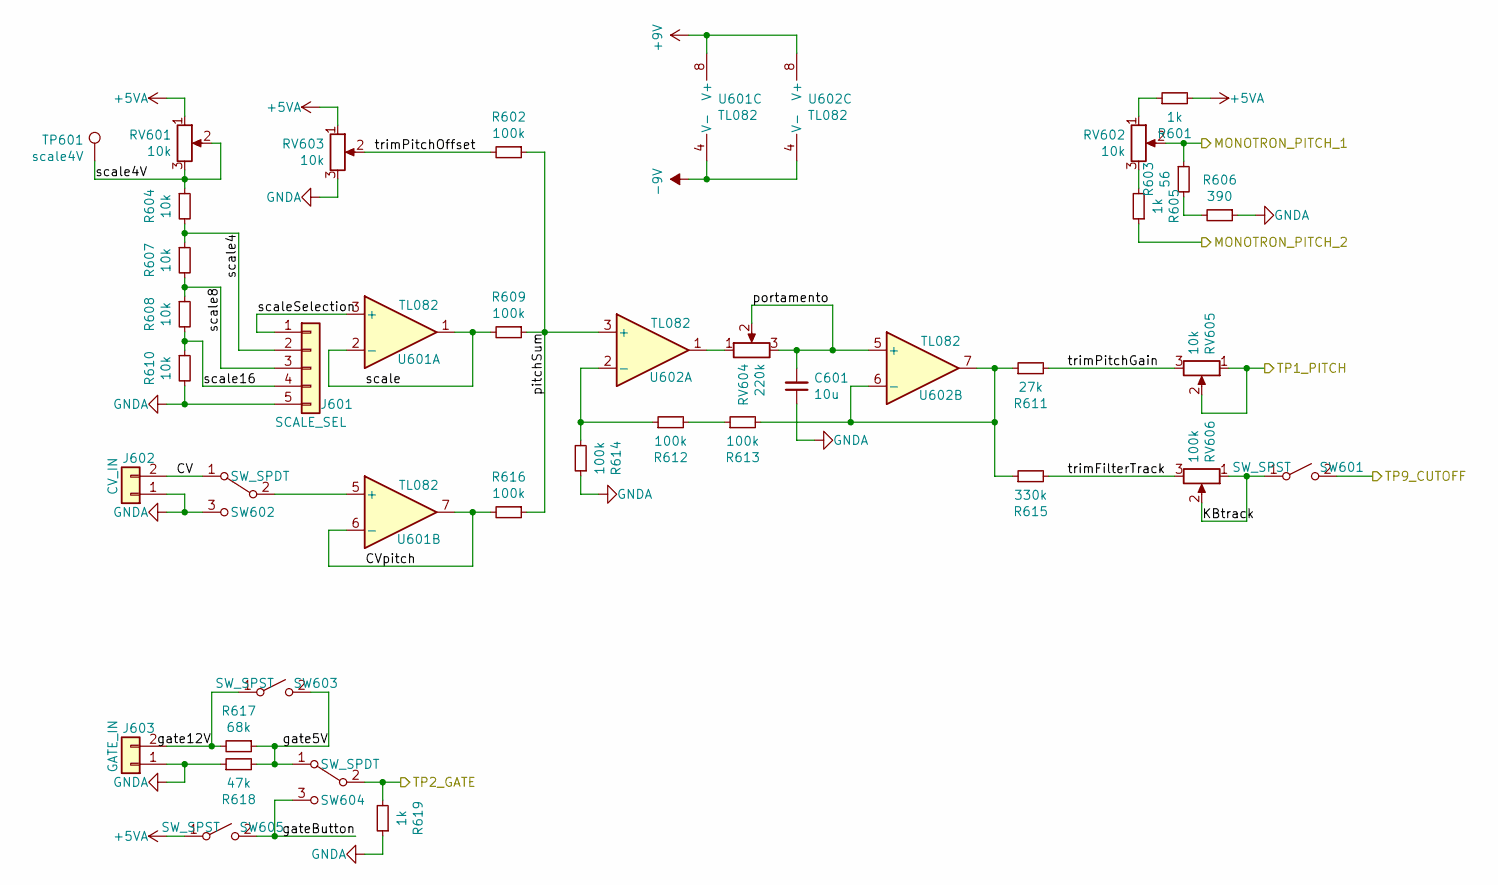
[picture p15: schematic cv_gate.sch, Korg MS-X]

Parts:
C601: 10u; C_0805_2012Metric_Pad1.18x1.45mm_HandSolder; LCSC C15850
J601: SCALE_SEL; PinHeader_1x05_P2.54mm_Vertical
J602: CV_IN; PinHeader_1x02_P2.54mm_Vertical
J603: GATE_IN; PinHeader_1x02_P2.54mm_Vertical
R601, R605, R619: 1k; R_0805_2012Metric_Pad1.20x1.40mm_HandSolder; LCSC C17513
R602, R609, R612, R613, R614, R616: 100k; R_0805_2012Metric_Pad1.20x1.40mm_HandSolder; LCSC C149504
R603: 56; R_0805_2012Metric_Pad1.20x1.40mm_HandSolder; LCSC C17757
R604, R607, R608, R610: 10k; R_0805_2012Metric_Pad1.20x1.40mm_HandSolder; LCSC C17414
R606: 390; R_0805_2012Metric_Pad1.20x1.40mm_HandSolder; LCSC C17655
R611: 27k; R_0805_2012Metric_Pad1.20x1.40mm_HandSolder; LCSC C17593
R615: 330k; R_0805_2012Metric_Pad1.20x1.40mm_HandSolder; LCSC C17629
R617: 68k; R_0805_2012Metric_Pad1.20x1.40mm_HandSolder; LCSC C17801
R618: 47k; R_0805_2012Metric_Pad1.20x1.40mm_HandSolder; LCSC C17713
RV601, RV603, RV605: 10k; Potentiometer_Bourns_3296W_Vertical
RV602: 10k; PinHeader_1x03_P2.54mm_Vertical
RV604: 220k; PinHeader_1x03_P2.54mm_Vertical
RV606: 100k; Potentiometer_Bourns_3296W_Vertical
SW601, SW603, SW605: SW_SPST; PinHeader_1x02_P2.54mm_Vertical
SW602, SW604: SW_SPDT; PinHeader_1x03_P2.54mm_Vertical
TP601: scale4V; TestPoint_THTPad_2.0x2.0mm_Drill1.0mm
U601, U602: TL082; SOIC-8_3.9x4.9mm_P1.27mm; LCSC C9385

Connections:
+5VA: R601.2, RV601.1, RV603.1, SW605.1 (A); also elsewhere on the board
+9V: U601.8 (V+), U602.8 (V+); also elsewhere on the board
-9V: U601.4 (V-), U602.4 (V-); also elsewhere on the board
/MONOTRON_PITCH_1: R603.1, RV602.2; also elsewhere on the board
/MONOTRON_PITCH_2: R605.1; also elsewhere on the board
/TP1_PITCH: RV605.1, RV605.2; also elsewhere on the board
/TP2_GATE: R619.2, SW604.2 (B); also elsewhere on the board
/TP9_CUTOFF: SW601.2 (B); also elsewhere on the board
/cv_gate/CV: J602.2, SW602.1 (A)
/cv_gate/CVpitch: R616.2, U601.6 (-), U601.7
/cv_gate/KBtrack: RV606.1, RV606.2, SW601.1 (A)
/cv_gate/gate5V: R617.1, R618.2, SW603.2 (B), SW604.1 (A)
/cv_gate/gate12V: J603.2, R617.2, SW603.1 (A)
/cv_gate/gateButton: SW604.3 (C), SW605.2 (B)
/cv_gate/pitchSum: R602.1, R609.1, R616.1, U602.3 (+)
/cv_gate/portamento: C601.2, RV604.2, RV604.3, U602.5 (+)
/cv_gate/scale: R609.2, U601.1, U601.2 (-)
/cv_gate/scale4: J601.2, R604.2, R607.1
/cv_gate/scale4V: R604.1, RV601.2, RV601.3, TP601.1
/cv_gate/scale8: J601.3, R607.2, R608.1
/cv_gate/scale16: J601.4, R608.2, R610.1
/cv_gate/scaleSelection: J601.1, U601.3 (+)
/cv_gate/trimFilterTrack: R615.2, RV606.3
/cv_gate/trimPitchGain: R611.2, RV605.3
/cv_gate/trimPitchOffset: R602.2, RV603.2
GNDA: C601.1, J601.5, J602.1, J603.1, R606.1, R610.2, R614.1, R618.1, R619.1, RV603.3, SW602.3 (C); also elsewhere on the board
unnamed: R601.1, RV602.1
unnamed: R603.2, R606.2
unnamed: R605.2, RV602.3
unnamed: R611.1, R613.2, R615.1, U602.6 (-), U602.7
unnamed: R612.1, R614.2, U602.2 (-)
unnamed: R612.2, R613.1
unnamed: RV604.1, U602.1
unnamed: SW602.2 (B), U601.5 (+)

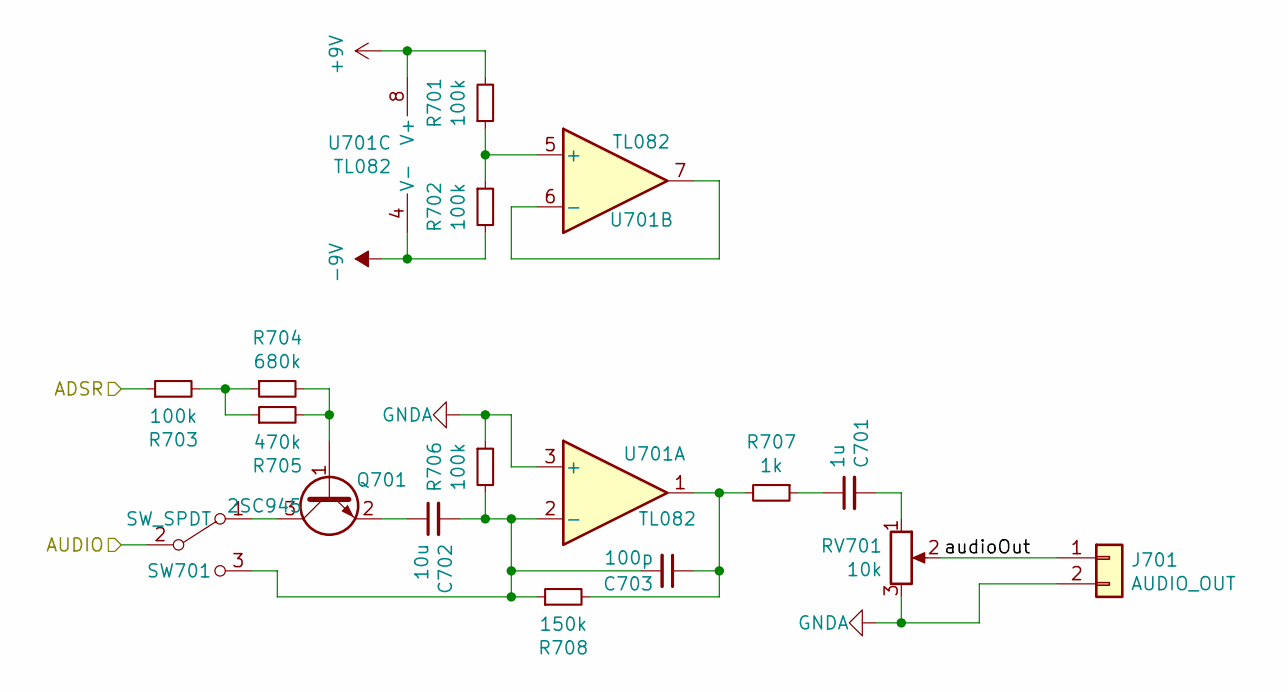
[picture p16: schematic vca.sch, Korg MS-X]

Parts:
C701: 1u; C_0805_2012Metric_Pad1.18x1.45mm_HandSolder; LCSC C28323
C702: 10u; C_0805_2012Metric_Pad1.18x1.45mm_HandSolder; LCSC C15850
C703: 100p; C_0805_2012Metric_Pad1.18x1.45mm_HandSolder; LCSC C1790
J701: AUDIO_OUT; PinHeader_1x02_P2.54mm_Vertical
Q701: 2SC945; SOT-23; LCSC C181154
R701, R702, R703, R706: 100k; R_0805_2012Metric_Pad1.20x1.40mm_HandSolder; LCSC C149504
R704: 680k; R_0805_2012Metric_Pad1.20x1.40mm_HandSolder; LCSC C17797
R705: 470k; R_0805_2012Metric_Pad1.20x1.40mm_HandSolder; LCSC C17709
R707: 1k; R_0805_2012Metric_Pad1.20x1.40mm_HandSolder; LCSC C17513
R708: 150k; R_0805_2012Metric_Pad1.20x1.40mm_HandSolder; LCSC C17470
RV701: 10k; PinHeader_1x03_P2.54mm_Vertical
SW701: SW_SPDT; PinHeader_1x03_P2.54mm_Vertical
U701: TL082; SOIC-8_3.9x4.9mm_P1.27mm; LCSC C9385

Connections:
+9V: R701.2, U701.8 (V+); also elsewhere on the board
-9V: R702.2, U701.4 (V-); also elsewhere on the board
/ADSR: R703.1; also elsewhere on the board
/AUDIO_RESONANCE: SW701.2 (B); also elsewhere on the board
/vca/audioOut: J701.1, RV701.2
GNDA: J701.2, R706.1, RV701.3, U701.3 (+); also elsewhere on the board
unnamed: C701.1, R707.1
unnamed: C701.2, RV701.1
unnamed: C702.1, Q701.2 (E)
unnamed: C702.2, C703.2, R706.2, R708.1, SW701.3 (C), U701.2 (-)
unnamed: C703.1, R707.2, R708.2, U701.1
unnamed: Q701.1 (B), R704.2, R705.2
unnamed: Q701.3 (C), SW701.1 (A)
unnamed: R701.1, R702.1, U701.5 (+)
unnamed: R703.2, R704.1, R705.1
unnamed: U701.6 (-), U701.7

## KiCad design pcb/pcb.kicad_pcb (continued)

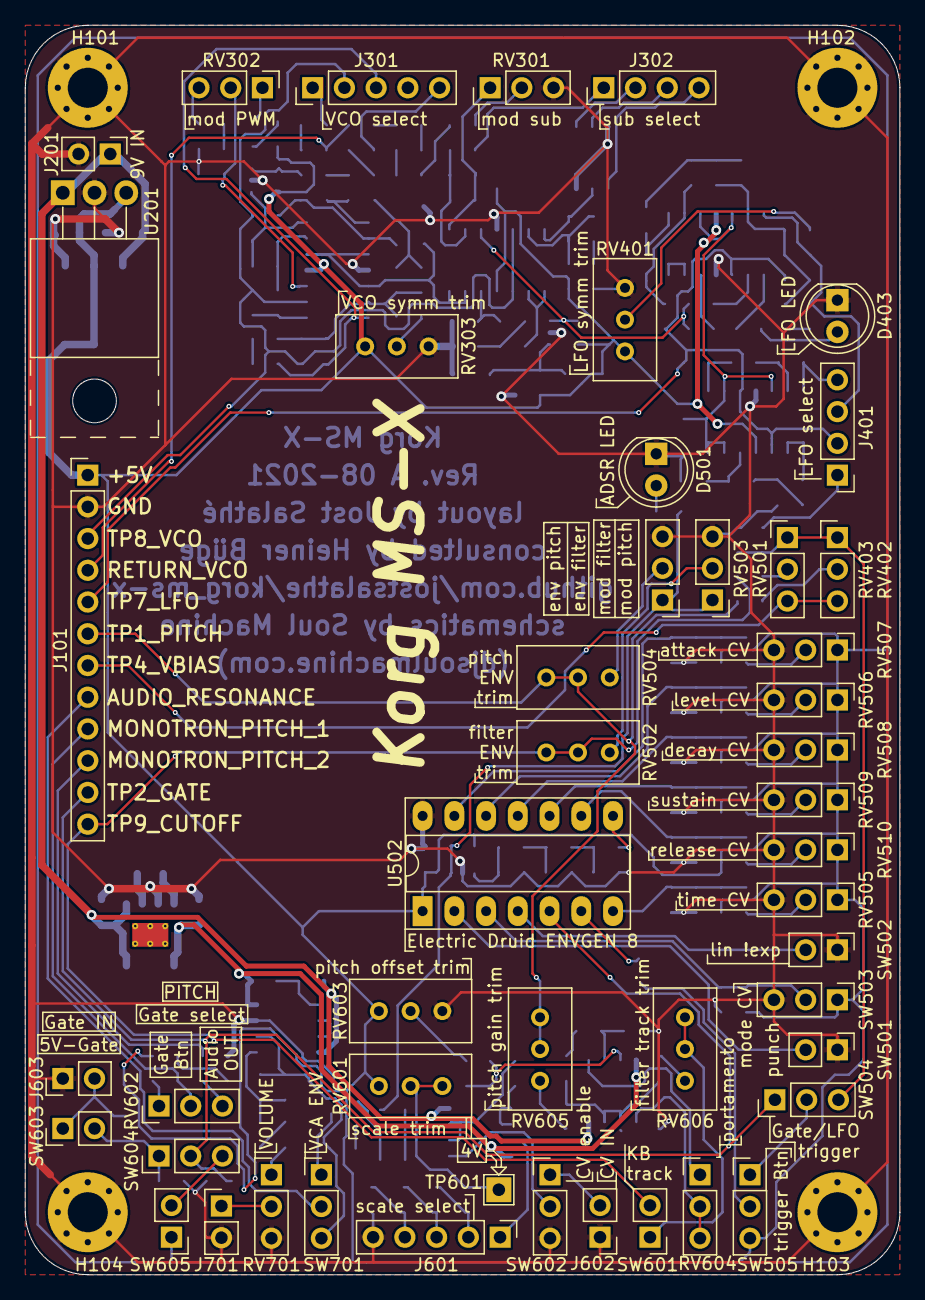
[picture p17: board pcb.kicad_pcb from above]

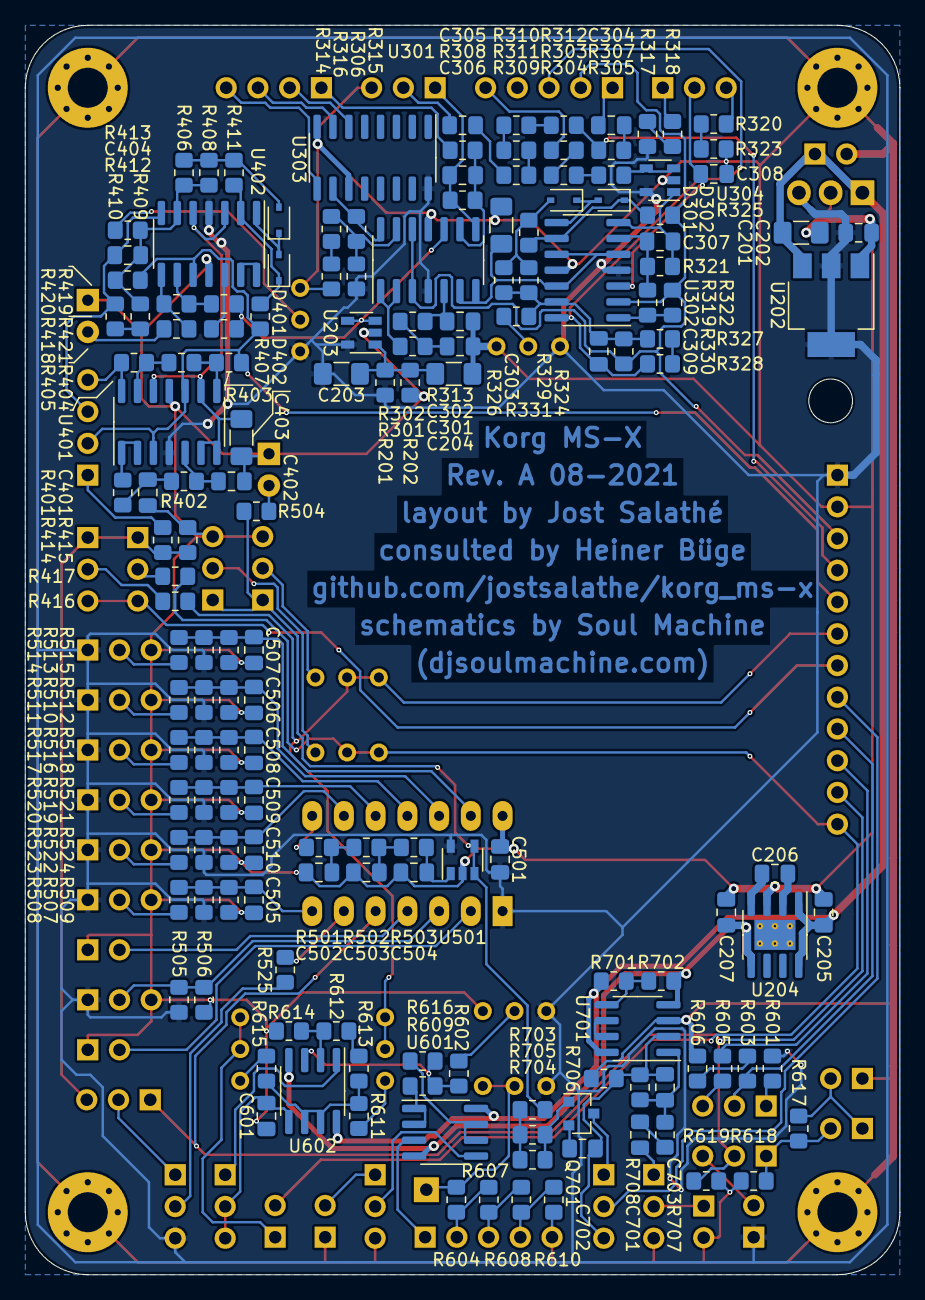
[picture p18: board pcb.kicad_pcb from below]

Board: 2 copper layers, 70.0 x 100.0 mm, 211 parts (159 on the bottom side), 143 nets.

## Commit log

2021-07-20 initialized KiCAD project
    [pcb.kicad_pcb, pcb.sch]
2021-07-21 Finished power supply schematics.
    [pcb.sch, power.sch]
2021-07-21 Added some packages and the 2V5 reference voltage as well as first parts for the VCO.
    [pcb.sch, power.sch, vco.sch]
2021-07-21 Added PDF of schematics
2021-07-27 Finished the VCO schematics. Some footprints still missing, though.
    [pcb.sch, vco.sch]
2021-07-28 Finished lfo schematics and rectified some errors
    [lfo.sch, pcb.sch, power.sch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]
2021-07-28 forgot schematics PDF
2021-07-30 Added and finished ADSR circuitry.
    [adsr.sch, lfo.sch, pcb.sch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]
2021-07-31 Added and finished CV/GATE circuitry.
    [adsr.sch, cv_gate.sch, lfo.sch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]
2021-07-31 Forgot to plot current state of schematics, again... :facepalm:
2021-08-21 Finished all schematics.
    [adsr.sch, cv_gate.sch, lfo.sch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]
2021-08-21 Completed most of the layout. ADSR and CV circuitry still in progress...
    [cv_gate.sch, lfo.sch, pcb.kicad_pcb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]
2021-08-21 Finished routing of signals. RTemaining tasks are marking the pcb and cleaning up the silk screen.
    [adsr.sch, lfo.sch, pcb.kicad_pcb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]
2021-08-23 Finished Rev.A layout.
    [adsr.sch, cv_gate.sch, lfo.sch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]
2021-08-27 Changed RV605 and RV606 positions.
    [pcb.kicad_pcb]
2021-08-27 Added JLCPCB part numbers to symbols and generated production files.
    [adsr.sch, cv_gate.sch, korg_ms-x_BOM.csv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]
2021-08-28 Added a selector for sub oscillator octave. Aaaaand added Heiner Büge as consultant to the back copper layer.
    [pcb.kicad_pcb, vco.sch]
2021-08-29 Modified the 50 Ohm resistor to 47 Ohm due to availability. This should have no effect on the synthesis. Routed signals for sub oscillator selection.
    [adsr.sch, cv_gate.sch, korg_ms-x_BOM.csv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]
2021-09-12 Added note about the optionality of the pull-up and -down resistors on the ADSR CV inputs.
    [adsr.sch, pcb.kicad_pcb]
